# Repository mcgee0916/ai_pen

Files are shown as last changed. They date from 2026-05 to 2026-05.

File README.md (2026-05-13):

# AI PEN — 智慧軌跡筆
Gemini_Generated_Image_a84ghia84ghia84g

以 YOLOv4-Tiny 為推論核心的手寫數學式辨識裝置。使用者以實體筆在空中或紙上書寫數字與運算符號，裝置即時辨識並在 OLED 顯示計算結果。

\---

## 硬體規格

|元件|說明|
|-|-|
|MCU|HUB-8735Ultra|
|軌跡感測器|PAA5163D 光學感測器（Serial3，115200 baud）|
|顯示器|SSD1306 OLED（I2C）|
|按鈕|Pin 15，INPUT\_PULLUP|
|儲存|SD 卡（VFS FAT）|
|神經網路|NNObjectDetectionImage（板載 NPU）|

3D 列印外殼檔案：`ai\\\_pan\\\_frame.stl`

\---

## 辨識類別（14 類）

|類別|標籤|
|-|-|
|數字|`0` `1` `2` `3` `4` `5` `6` `7` `8` `9`|
|運算子|`add` (+)、`sub` (-)、`mul` (×)、`div` (÷)|

\---

## 目錄結構

```
.
├── ai\\\_pan/                  ← 主韌體（辨識 + 計算機）
│   ├── ai\\\_pan.ino
│   └── OledDisplay.h
├── ai\\\_pan\\\_collect/          ← 資料收集韌體（建立訓練集用）
│   ├── ai\\\_pan\\\_collect.ino
│   └── OledDisplay.h
├── NN\\\_MDL/
│   └── yolov4\\\_tiny.nb       ← 編譯完成的模型權重（燒錄至 SD 卡）
├── Unit\\\_testing/            ← 元件單元測試草稿
│   ├── BTN/                 ← 按鈕測試
│   ├── OLED/                ← OLED 顯示測試
│   ├── OLED\\\_BTN/            ← OLED + 按鈕整合測試
│   ├── PAA5163D/            ← 光學感測器測試
│   ├── ALL/                 ← 全元件整合測試
│   ├── HUB-PAA5163D\\\_Tracker.exe           ← Windows 軌跡可視化工具
│   └── HUB-PAA5163D\\\_路徑測試程式使用說明.pdf
├── YOLOv4Tiny\\\_AutoTrain.ipynb  ← Google Colab 訓練 Notebook
├── ai\\\_pan\\\_frame.stl            ← 外殼 3D 列印檔
└── AI-PEN.pptx                 ← 專案簡報
```

\---

## 環境建置

### 步驟 1：安裝 Arduino IDE

前往 [arduino.cc/en/software](https://www.arduino.cc/en/software) 下載並安裝 **Arduino IDE 1.8.19 或 2.x**。

### 步驟 2：新增開發板來源 URL

開啟 Arduino IDE → **檔案 → 偏好設定**，在「額外的開發板管理員網址」貼上：

```
https://github.com/ideashatch/HUB-8735/raw/main/amebapro2\_arduino/Arduino\_package/ideasHatch.json
```

點選 OK 儲存。

### 步驟 3：安裝開發板套件

**工具 → 開發板 → 開發板管理員**，搜尋 `ideasHatch` 或 `8735`，安裝 **HUB8735ULTRA**。
出現 `Platform ideasHatch:AmebaPro2@4.1.1-Release installed` 即完成。

### 步驟 4：安裝函式庫

**工具 → 管理函式庫**，分別搜尋並安裝：

|函式庫|用途|
|-|-|
|JPEGENC|AI辨識影像處理|

> `cJSON` 與 `NNObjectDetectionImage` 已包含在 ideasHatch SDK 中，無需額外安裝。

### 步驟 5：連接裝置與設定 COM Port

1. 用 USB Type-C 線連接 HUB 8735 Ultra 與電腦
2. **工具 → 開發板** 選擇 `HUB-8735\_ultra`（AmebaPro2 ARM 32-bits Boards - ideasHatch）
3. **工具 → 序列埠** 選擇對應 COM Port（Windows 裝置管理員確認 USB-SERIAL 編號）

\---

## 快速開始

### 1\. 準備 SD 卡

1. 將 SD 卡格式化為 **FAT32**
2. 將 `NN\_MDL\\yolov4\_tiny.nb` 連同資料夾複製到 SD 卡**根目錄**（路徑：`sd:NN\_MDL\\yolov4\_tiny.nb`）
3. 插入 HUB 8735 Ultra 的 SD 卡槽

### 2\. 硬體接線

|元件|元件接腳|HUB 8735 Ultra 接腳|
|-|-|-|
|HUB-PAA5163D|UART TX|Pin 5 (SERIAL3\_RX)|
|HUB-PAA5163D|UART RX|Pin 6 (SERIAL3\_TX)|
|HUB-PAA5163D|5V|5V|
|HUB-PAA5163D|GND|GND|
|SSD1306 OLED|SDA|Pin 0 (I2C1 SDA)|
|SSD1306 OLED|SCL|Pin 1 (I2C1 SCL)|
|SSD1306 OLED|VCC|5V|
|SSD1306 OLED|GND|GND|
|按鈕|S|Pin 15|
|按鈕|VCC|中間腳|
|按鈕|GND|GND|

### 3\. 燒錄韌體

開啟 `ai\\\_pan/ai\\\_pan.ino`，先讓裝置進入 Bootloader 模式再上傳：

**方法 A（按鍵操作）：**

1. USB Type-C 連接電腦
2. 長按「功能鍵」（不放開）
3. 按一下「Reset 鍵」後放開
4. 放開「功能鍵」→ 裝置進入 Bootloader 模式

**方法 B（短路 BOOT 引腳）：**

1. 短接 `BOOT\_MODE`（Pin 14）與 `BOOT\_V3P3`（3.3V）
2. 按下 Reset 後放開，再移除跳線

進入 Bootloader 後，點選 **上傳（Ctrl+U）**，輸出視窗出現 `Start Upload Flash → End Upload Flash` 即成功。上傳完成後按 Reset 重啟。

### 4\. 按鈕操作

|手勢|功能|
|-|-|
|長按（≥300 ms）按住|開始書寫軌跡|
|長按放開|結束書寫|
|單擊|清除目前筆畫|
|雙擊|觸發辨識|
|三擊|清除整條算式|
|四擊|重新初始化 PAA5163D|

### 4\. 書寫流程

1. **長按** → 書寫一個字元 → **放開**
2. 確認 OLED 預覽正確後 **雙擊** 觸發辨識
3. 辨識結果自動附加至算式；算式完整（數字＋運算子＋數字）時立即計算並顯示結果
4. **三擊**清除算式，重新開始

\---

## 訓練自訂模型

使用 `YOLOv4Tiny\\\_AutoTrain.ipynb`（需 Google Colab GPU）：

1. 在 Google Drive 建立 `yolov4\\\_tiny\\\_training/dataset/` 資料夾
2. 上傳圖片與對應 YOLO 格式 `.txt` 標註（`class\\\_id cx cy w h`，相對比例）
3. 在 Notebook 第一個 Cell 設定類別名稱與超參數
4. 依序執行所有 Cell；最佳權重輸出至 `yolov4\\\_tiny\\\_training/backup/`
5. 將 `.weights` 轉為 `.nb` 格式後複製至 SD 卡

\---

## 元件單元測試

開發或除錯時可先燒錄對應的單元測試草稿，確認硬體功能正常：

|草稿|測試目標|
|-|-|
|`Unit\\\_testing/BTN/BTN.ino`|按鈕長按 / 雙擊事件|
|`Unit\\\_testing/OLED/OLED.ino`|OLED 顯示輸出|
|`Unit\\\_testing/OLED\\\_BTN/OLED\\\_BTN.ino`|OLED + 按鈕整合|
|`Unit\\\_testing/PAA5163D/PAA5163D.ino`|PAA5163D 軌跡串流|
|`Unit\\\_testing/ALL/ALL.ino`|全元件整合|

Windows 上可用 `HUB-PAA5163D\\\_Tracker.exe` 將 PAA5163D 的 X/Y 串流可視化，確認感測器路徑是否正確。

\---

## SD 卡檔案說明

裝置啟動時會自動建立以下檔案：

|路徑|用途|
|-|-|
|`sd:/char-0001.jpg`|最近一次書寫的 JPEG 圖（推論輸入）|
|`sd:/char-0001.json`|NPU 輸出的偵測結果 JSON|
|`sd:/char\\\_list.txt`|推論圖片清單|
|`sd:/calc\\\_state.txt`|算式狀態（斷電保留）|
|`sd:/recognized/`|每次辨識後的 BMP 快照（用於資料收集）|

\---

## 開發環境

* Arduino IDE（含 Ameba RTL8720 BSP）
* &#x20;Google Colab（模型訓練）
* 相依函式庫：`JPEGENC`、`NNObjectDetectionImage`、`cJSON`、`SSD1306`

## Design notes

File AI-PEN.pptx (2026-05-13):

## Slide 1

AI-PEN

國產IC x ALgoHUB 智造實作日
HUB-8735Ultra x HUB-PAA5163D
HUB-PAA5163D 智慧軌跡筆

本專題使用的元件清單

HUB 8735 Ultra

開發板

HUB-PAA5163D
光學流量感測模組

感測器

SSD1306
128×32 OLED

顯示器

YOLOv4-Tiny
14 類手寫識別

AI 模型

瑞創框架科技股份有限公司
Recsframe Technology

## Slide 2

01

專題概述

本課程所需程式碼連結:
https://github.com/mcgee0916/ai_pen

這個專題要解決什麼問題？

SD 卡
模型 + 資料

HUB 8735 Ultra
主控板

YOLOv4-Tiny
AI 模型 (.nb)

推論

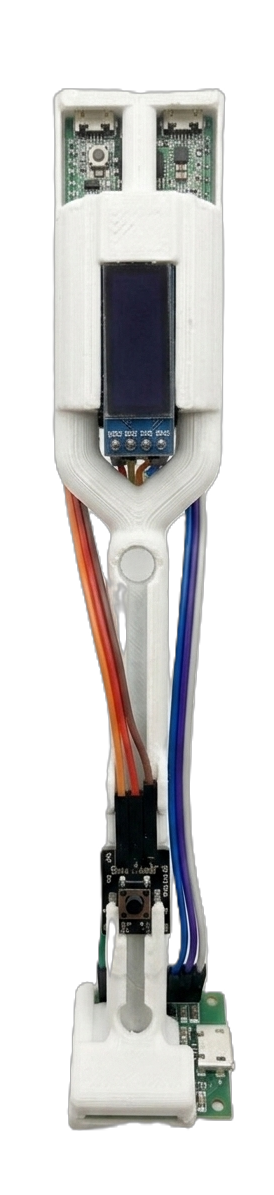
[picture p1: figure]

SSD1306
OLED

傳統計算機需要按鍵輸入，不夠直覺
→ 能不能用「手寫」來輸入數學算式？
→ 讓嵌入式裝置直接辨識手寫筆跡，自動計算結果

AI-PEN 的運作流程

微動按鈕模組

① 用筆在感測器上方書寫數字或運算符號
② HUB-PAA5163D 感測器捕捉筆尖移動軌跡（X/Y 座標）
③ HUB 8735 Ultra 將軌跡轉換成 128×128 點陣圖
④ 內建 YOLOv4-Tiny 模型辨識是哪個數字/符號
⑤ 累積算式後計算結果，顯示在 OLED 螢幕上

HUB-PAA5163D
光流感測器

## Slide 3

02

HUB 8735 Ultra — 介紹

HUB 8735 Ultra 是什麼？

HUB 8735 Ultra 是一款由振邦科技（WinsTec）推出的 AIoT 開發板，搭載瑞昱（Realtek）RTL8735B 晶片。
它的外型大小約為 Arduino Uno 的一半，但功能遠超傳統 Arduino：內建 Wi-Fi、BLE、攝影機介面，並支援硬體 AI 推論加速。
透過 Arduino IDE 開發，降低嵌入式 AI 的入門門檻。

功能 | HUB 8735 Ultra
處理器 | 32-bit ARM Cortex-A @ 500MHz
無線通訊 | Wi-Fi 2.4/5GHz BLE 4.2 RTSP
攝影機 | FPC 攝影機介面（最高 FHD 30fps）
AI 推論 | 支援多種辨識模型
電源 | USB Type-C 5V
尺寸 | 53 × 27 mm
其他 | LED燈、多組UART介面、I2C、SPI

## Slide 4

03

OLED VCC

HUB 8735 Ultra — 硬體規格與腳位

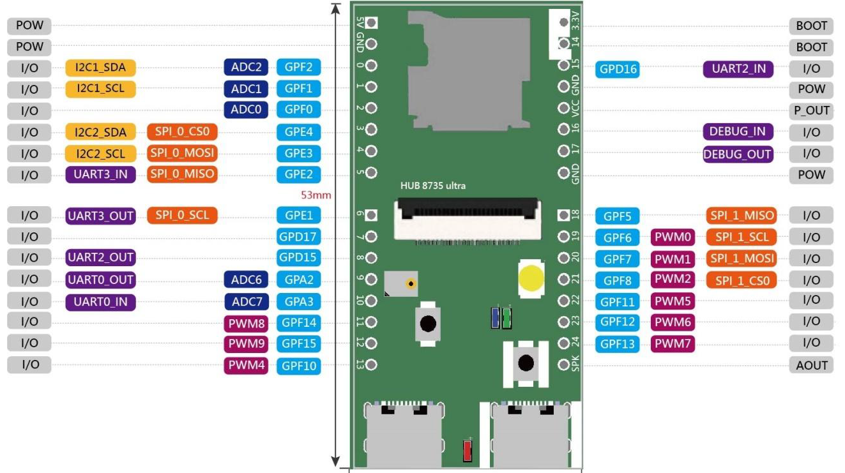
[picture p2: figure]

OLED GND

按鈕 VCC(中間)

按鈕 S

按鈕 GND(-)

OLED SDA
OLED SCL

PAA UART RX

PAA 5V

PAA UART TX

PAA GND

12-bit

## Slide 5

04

步驟 1

HUB 8735 Ultra — Arduino IDE 環境設定

安裝 Arduino IDE ≥ 1.8.19

前往 arduino.cc/en/Main/Software 下載並安裝。
建議使用 1.8.19 或 2.x 版，支援第三方開發板套件。

步驟 2

新增開發板來源 URL

開啟 Arduino IDE → 檔案 → 偏好設定
在「其他開發板管理員網址」貼上：
github.com/ideashatch/HUB-8735/raw/main/amebapro2_arduino/Arduino_package/ideasHatch.json

步驟 3

安裝開發板套件

工具 → 開發板 → 開發板管理員
搜尋「HUB 8735 ultra」或「ideasHatch」
找到「IdeasHatch Ameba Boards (32-bit ARM v8M @500MHz)」
安裝版本 4.0.10-Release 或更新版

步驟 4

連接裝置 COM Port 設置

用 USB Type-C 線連接電腦，並設置上傳程式預先流程。 （Windows 裝置管理員可確認 USB-SERIAL 的編號）
開發板 → AmebaPro2 ARM(32-bits) Boards - ideasHatch
→ 選擇「HUB-8735_ultra」

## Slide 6

04

步驟 1

HUB 8735 Ultra — Arduino IDE 環境設定

安裝 Arduino IDE ≥ 1.8.19

前往 arduino.cc/en/Main/Software 下載並安裝。
建議使用 1.8.19 或 2.x 版，支援第三方開發板套件。

https://www.arduino.cc/en/software/

1

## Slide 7

04

步驟 2

HUB 8735 Ultra — Arduino IDE 環境設定

新增開發板來源 URL

開啟 Arduino IDE → 檔案 → 偏好設定
在「其他開發板管理員網址」貼上：github.com/ideashatch/HUB-8735/raw/main/amebapro2_arduino/Arduino_package/ideasHatch.json
並點選OK 儲存設定

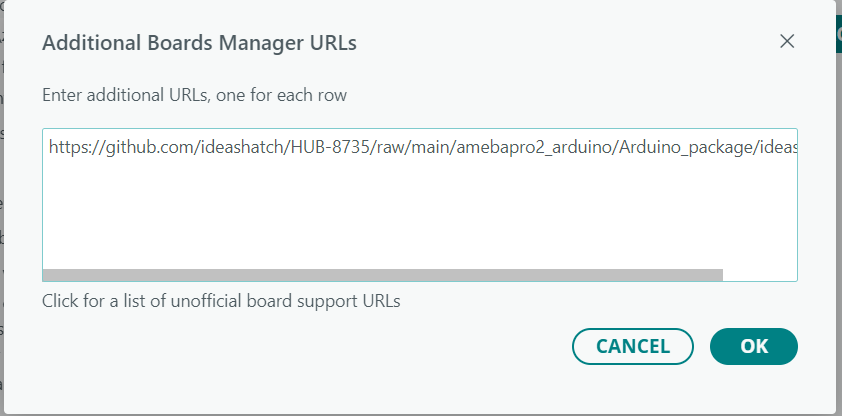
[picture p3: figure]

在空白處貼上網址

3

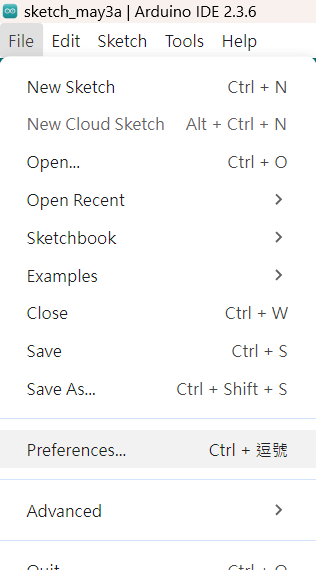
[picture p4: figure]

點選OK 儲存

4

1

2

github.com/ideashatch/HUB-8735/raw/main/amebapro2_arduino/Arduino_package/ideasHatch.json

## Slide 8

04

步驟 3

HUB 8735 Ultra — Arduino IDE 環境設定

安裝開發板套件

點選Board Manager 並在輸入框輸入” ideasHatch “ 或 ”8735”，將HUB8735ULTRA的韌體安裝。

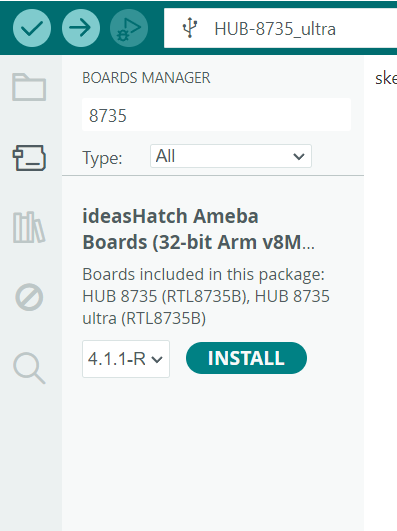
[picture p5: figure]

1

2

顯示Platform ideasHatch:AmebaPro2@4.1.1-Release installed
代表安裝完成!

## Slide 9

04

步驟 4

HUB 8735 Ultra — Arduino IDE 環境設定

連接裝置 COM Port 設置

用 USB Type-C 線連接電腦，並設置上傳程式預先流程。 （Windows 裝置管理員可確認 USB-SERIAL 的編號）

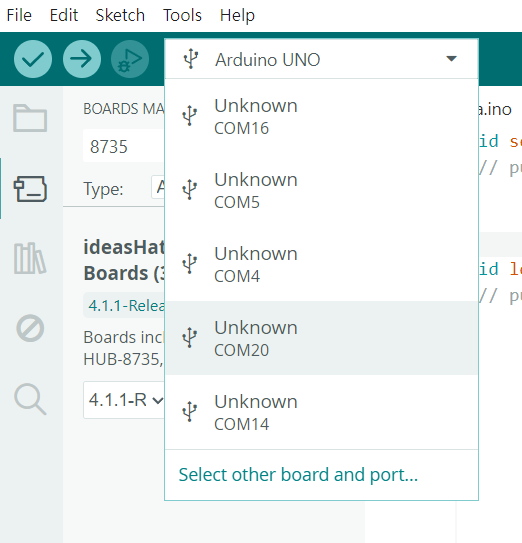
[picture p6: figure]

選擇設備連接後 出現的unknow COM port

BOARDS 輸入8735 並選擇HUB-8735_ultra

Type C線 連接HUB8735Ultra 及電腦

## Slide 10

05

HUB 8735 Ultra — 程式燒錄流程

燒錄準備：讓開發板進入 Bootloader（燒錄）模式

方法 A | 按鍵操作

方法 B | 短路 BOOT 引腳

① 用 USB Type-C 連接電腦
② 長按「功能鍵」（不放）
③ 按一下「Reset 鍵」後放開
④ 放開「功能鍵」
→ 裝置進入 Bootloader 模式

① 用跳線短接 BOOT_MODE（Pin 14）與 BOOT_V3P3（3.3V）

② 按下 Reset 鍵後放開

③ 移除跳線

→ 裝置進入 Bootloader 模式

（適合無法操作按鍵的場合）

程式上傳步驟

在 Arduino IDE 撰寫或開啟 .ino 專案

點選草稿碼 → 驗證/編譯（Ctrl+R），確認無錯誤

編寫程式

驗證編譯

依上方方法 A 或 B 讓裝置進入 Bootloader

進燒錄模式

點選上傳（Ctrl+U），觀察輸出視窗出現「Start Upload Flash → End Upload Flash」

上傳完成後按 Reset 鍵，程式開始執行

上傳

重啟

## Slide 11

05

HUB 8735 Ultra — 程式燒錄流程

燒錄準備：讓開發板進入 Bootloader（燒錄）模式

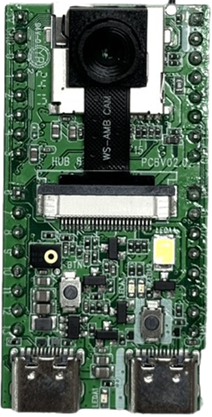
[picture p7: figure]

按住功能鍵

1

2

按住功能鍵狀態點擊
Reset鍵

方法 A | 按鍵操作

① 用 USB Type-C 連接電腦
② 長按「功能鍵」（不放）
③ 按一下「Reset 鍵」後放開
④ 放開「功能鍵」
→ 裝置進入 Bootloader 模式

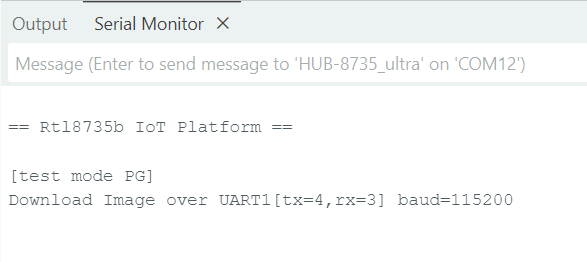
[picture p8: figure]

若成功進入Bootloader模式
可看到Serial Monitor顯示以上資訊

3

放開功能鍵

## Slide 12

06

HUB-PAA5163D — 光學流量感測原理

HUB-HUB-PAA5163D 模組外觀

PCB 板尺寸：約 35 × 35mm（郵票大小）
正面：HT32F49153 MCU + 感測器孔（朝下）
背面：PAA5163 光流鏡頭
接頭：USB-C（電源/UART）+ UART 引腳 + I2C 引腳

在 AI-PEN 中的接線方式

HUB-PAA5163D UART TX

HUB 8735 Ultra Pin 5 (SERIAL3_RX)

HUB-PAA5163D UART RX

HUB 8735 Ultra Pin 6 (SERIAL3_TX)

HUB-PAA5163D 5V

HUB-PAA5163D GND

HUB 8735 Ultra 5V

HUB 8735 Ultra GND

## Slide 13

06

HUB-PAA5163D — 光學流量感測原理

什麼是光學流量感測器（Optical Flow）？

光學流量感測器的原理類似光學滑鼠：
底部有一個微型攝影鏡頭，持續拍攝下方表面影像
比對連續兩張影像的像素移動，計算 X/Y 方向位移
輸出累積位移值（單位：counts per inch, CPI）
優點：不需要觸碰感測器，懸空即可感測
本專題應用：感測器朝下，筆在感測器下方 5–40mm 書寫

感測器 vs 滑鼠的比較

特性 | 電腦滑鼠 | HUB-HUB-PAA5163D
輸出 | 相對 X/Y 位移 | 累積 X/Y 座標
介面 | USB HID | UART / I2C
附加功能 | 無 | 陀螺儀 + 電子羅盤

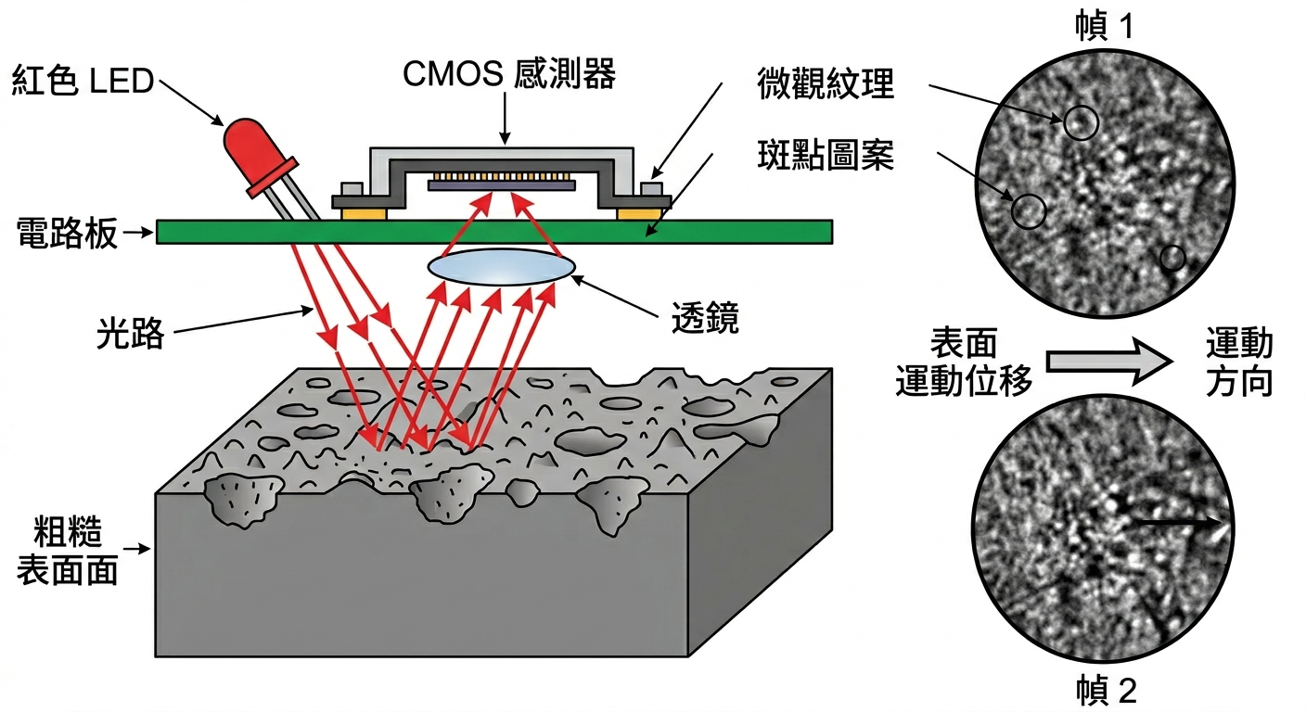
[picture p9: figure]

光學流量感測器

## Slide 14

06

HUB-PAA5163D — 光學流量感測原理

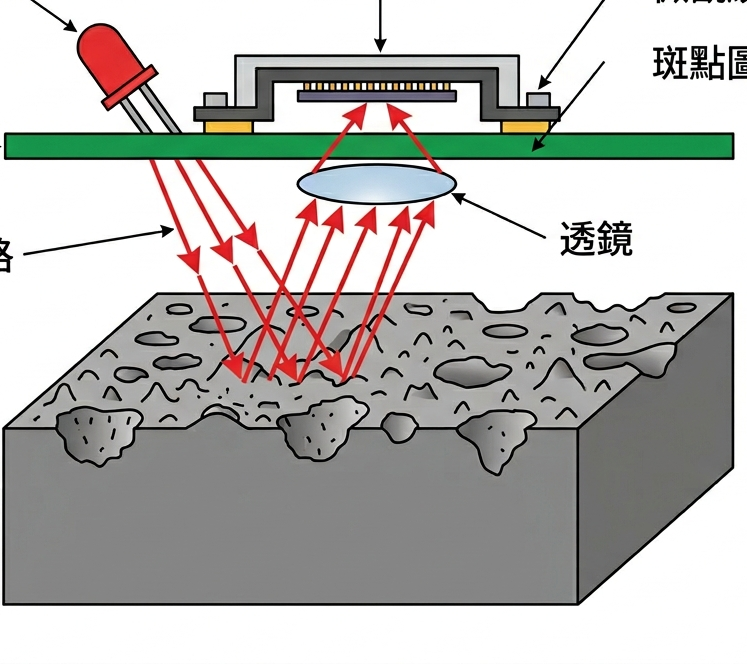
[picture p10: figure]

數據融合

讀取移動路徑

檢測傾腳、俯角

檢測方位

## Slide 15

07

HUB-PAA5163D — 硬體規格

MCU 控制器

PAA5163 光流感測器

1000 CPI-約 0.025 cm

ICM42688 六軸 IMU

QMC5883P 電子羅盤

型號

架構

HT32F49153

32-bit ARM Cortex-M4F

5 – 40 mm

解析度

感測高度

陀螺儀

加速度計

±2000 dps

±16g

量程

解析度

±8 Gauss

12-bit

時脈

144 MHz

>100 inch/s

最大速度

更新率

500 Hz

更新率

50 Hz

Flash

128KB

SPI（最高 2MHz）

介面

介面

I2C 400kHz

功能

傾斜補償

1KB（Flash 模擬）

電源規格

SRAM

EEPROM

48KB

5V（USB供電）

工作電壓

工作電流

約 150mA

功耗

約 0.75W

三種資料輸出模式（可切換）

ATR+ 原始模式

輸出原始位移量 dX, dY（整數）

ATX+ 座標模式

輸出累積絕對座標 X, Y

ATC+ 完整模式

輸出座標 + 陀螺儀 + 羅盤完整資料

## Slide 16

08

HUB-PAA5163D — 通訊介面：UART vs I2C

HUB-HUB-PAA5163D 提供兩種通訊介面，可根據應用選擇

特性 | UART / USB 介面 | I2C Slave 介面
主要用途 | 調試、測試、人機互動 | 嵌入式系統整合
控制方式 | AT 指令（文字） | 寄存器讀寫（二進位）
資料格式 | 文字或 JSON 格式 | 二進位結構體
通訊速率 | 115200 bps | 200 kHz
即時性 | 中（輪詢模式） | 高（直接記憶體存取）
適用場合 | PC 連接、除錯、示範 | MCU 對 MCU 通訊、量產品
啟用方式 | 上電預設啟用 | 偵測到 I2C 通訊自動切換
切換回 UART | 發送 UART 訊號即自動切換回 | 重新上電或硬體重置

本專題使用 UART 介面（Serial3, 115200bps）：MCU 解析 "X=NNN Y=NNN" 格式的文字輸出，取得手寫軌跡座標。
若偵測到 3 秒無資料，韌體會自動重新初始化感測器（發送 ATX+ 切換到座標模式）。

AI-PEN

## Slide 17

09

HUB-PAA5163D — AT 指令與資料格式

常用 AT 指令

說明

查詢通訊是否正常

指令

AT

資料輸出格式範例

JSON 模式（ATJ+ 後）

切換到原始模式（輸出 dX, dY）

ATR+

座標模式（ATX+）

切換到座標模式（輸出累積 X, Y）

ATX+

切換到完整模式（含 IMU、羅盤）

ATC+

A=5.4 X=0.0 Y=0.0 cA=304.2

{"A":6.1,"X":0.0,"Y":0.0,"cA":304.8}

啟用 JSON 格式輸出

ATJ+

韌體如何解析（ai_PEN.ino）

if (sscanf(line, "X=%d Y=%d", &x, &y) == 2) {
raw_pts[pt_count].x = x;
raw_pts[pt_count].y = y;
}

重設零點（目前位置設為 0,0）

AT0G+

重置感測器並重新初始化

ATNRST+OMT

設定報告間隔(50-1000)

ATRPT+

停止感測器資料輸出

ATM-

設定感測器距地面高度（影響精度）

ATH+[高度]

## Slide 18

09

HUB-PAA5163D — 設置

(確認裝置連線正常)

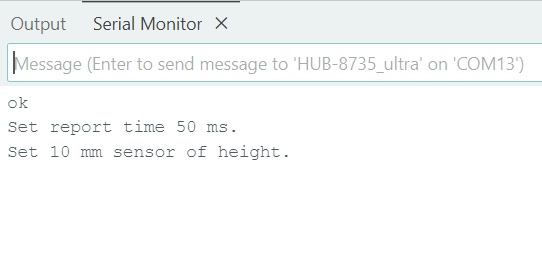
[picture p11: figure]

(設定回傳位置的時間間隔成功)

(設定感測的高度成功)

在Serial Monitor
依序輸入:

AT

atrpt+50

ath+10

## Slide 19

10

SSD1306 OLED — 規格與使用

Arduino 基本使用範例

SSD1306 是什麼？

SSD1306 是一款常見的單色 OLED 顯示器驅動 IC。
OLED（有機發光二極體）的特色：
· 自發光，不需背光，對比度高
· 低功耗，適合電池供電裝置
· 視角廣，響應速度快
· 本專題使用 128×32 像素尺寸

#include <Wire.h>
#include <Adafruit_GFX.h>
#include <Adafruit_SSD1306.h>

#define SCREEN_WIDTH 128
#define SCREEN_HEIGHT 32
Adafruit_SSD1306 display(SCREEN_WIDTH, SCREEN_HEIGHT, &Wire);

void setup() {
display.begin(SSD1306_SWITCHCAPVCC, 0x3C);
display.clearDisplay();
display.setTextColor(SSD1306_WHITE);
display.setTextSize(1);
display.setCursor(0, 0);
display.print("Hello AI-PEN!");
display.display(); // 必須呼叫才會更新畫面
}

硬體規格

128 × 32 像素（單色）

I2C（位址 0x3C 或 0x3D）

解析度

介面

3.3V / 5V 皆相容

電壓

I2C 接線（以 HUB 8735 Ultra 為例）

單色（白光 on 黑底）

Adafruit GFX + Adafruit SSD1306

顏色

HUB 8735 Pin 0（I2C1 SDA）

HUB 8735 Pin 1（I2C1 SCL）

HUB 8735 5V

HUB 8735 GND

OLED SDA

OLED SCL

OLED VCC

OLED GND

函式庫

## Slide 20

11

SSD1306 — OledDisplay.h 分區設計

為什麼要自定義 OledDisplay.h？

128×32 的螢幕空間有限，AI-PEN 需要同時顯示「筆跡預覽」和「算式 Token」，因此設計了 OledDisplay.h 將螢幕切成 2 個的區塊，各自獨立更新。

螢幕分區示意圖（128×32 總像素）

Section 1
筆跡預覽
32×32

Section 2
算式 Token
96×32

各區塊用途說明

左側最大區塊，顯示目前手寫筆跡的縮圖，或識別後的字符圖案

Section 0

右側三個區塊，各顯示一個已識別的算式 Token（數字或運算子）

Section 1–3

寫完一個字符雙擊識別後，Section 0 更新為 BMP 圖，Section 1/2/3 依序顯示算式

顯示邏輯

結果顯示在 Section 1–3，例如「3 + 5 = 8」，然後 sys_reset() 清除全部

計算完成

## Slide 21

11

SSD1306 — 接線

先將OLED卡入插槽

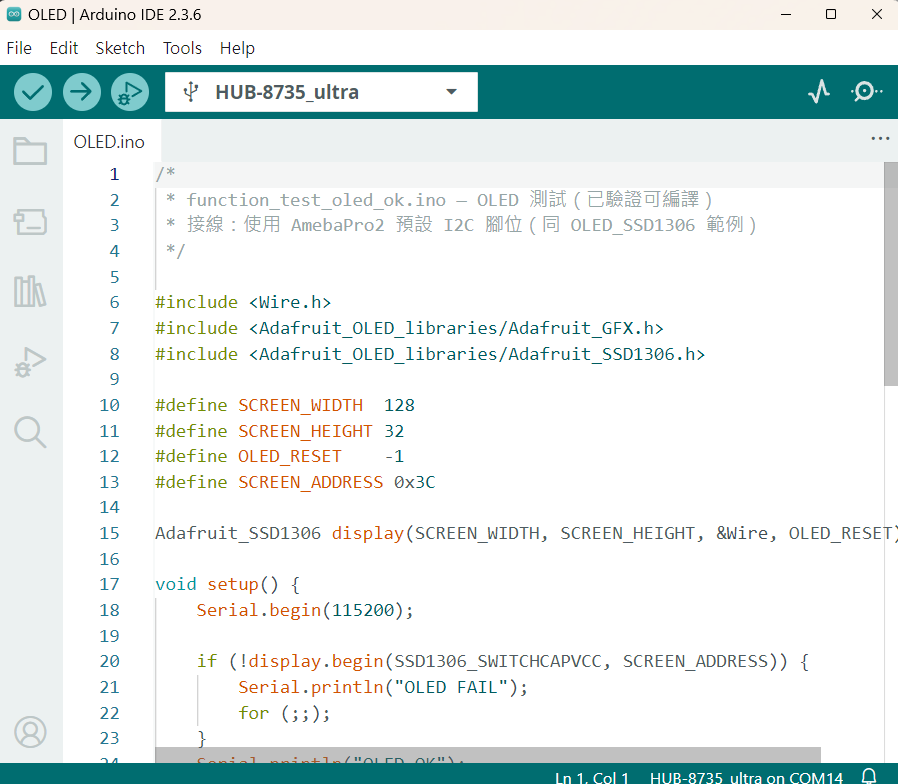
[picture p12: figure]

燒錄OLED 測試程式碼

OLED VCC
OLED GND
OLED SDA
OLED SCL

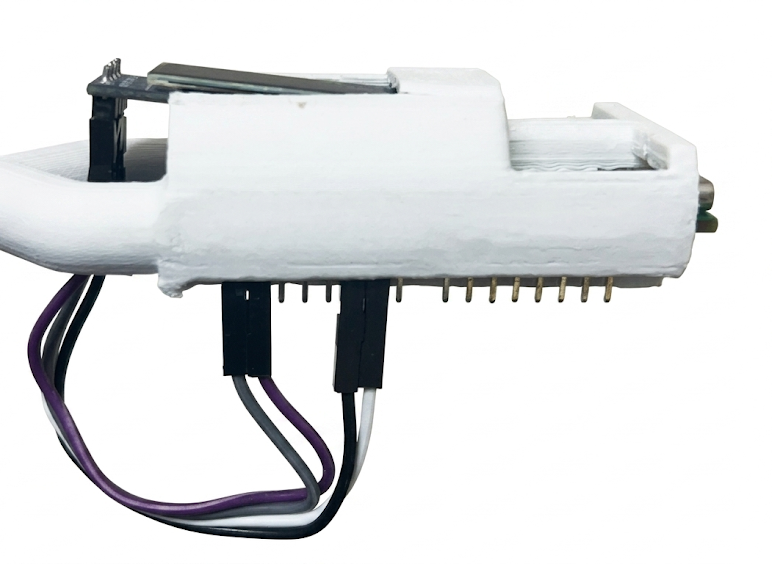
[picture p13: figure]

從筆桿中間位置穿孔連接杜邦線

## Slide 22

12

微動開關- 接線

將杜邦線先接上針腳
並將微動開關斜插進按鈕溝槽

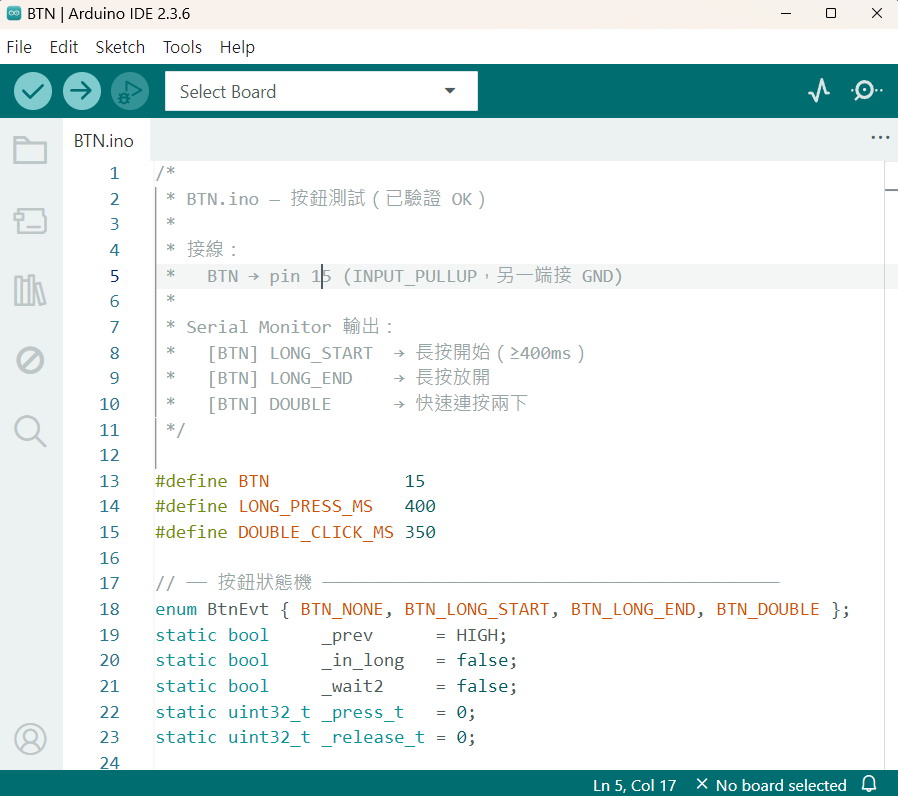
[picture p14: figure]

燒錄BTN程式碼確認接線
元件是否正常作動

按鈕 VCC(中間)

按鈕 S(15)

按鈕 GND(-)

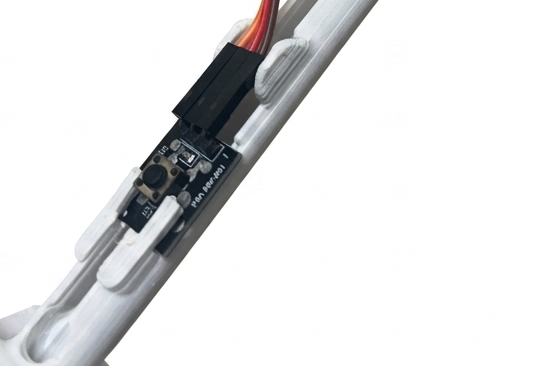
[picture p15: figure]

往前推之後，按鈕卡住即可

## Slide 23

13

HUB-PAA5163D - 接線

PAA 5V

PAA GND

PAA UART RX

PAA UART TX

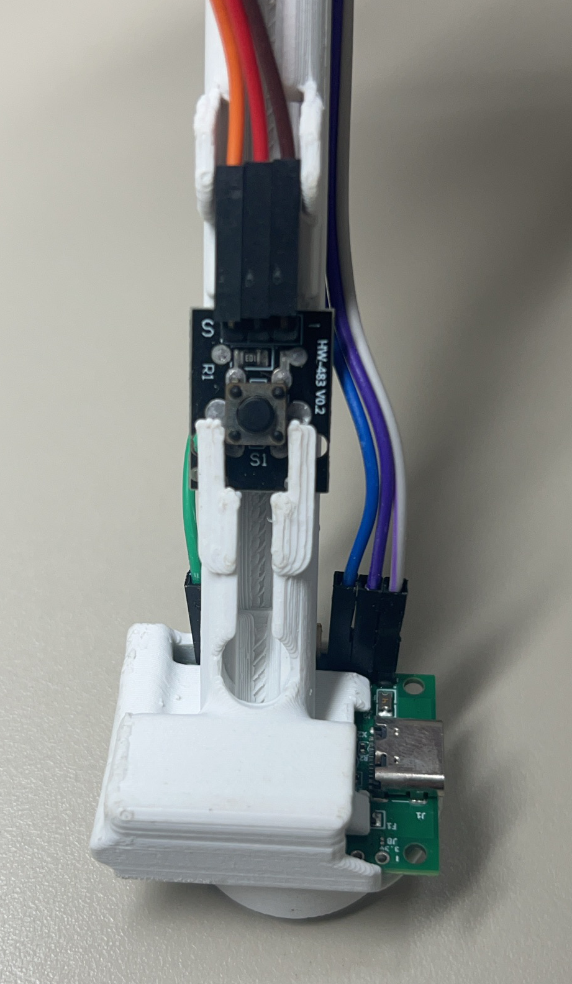
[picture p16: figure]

將PAA5163D插入元件孔位

將對應線接上(側面)

將對應線接上(背面)

(杜邦線同時會卡住PAA5163D使之不會鬆脫)

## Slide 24

13

HUB-PAA5163D - 接線

所有ai pen的所需元件都連接完成!

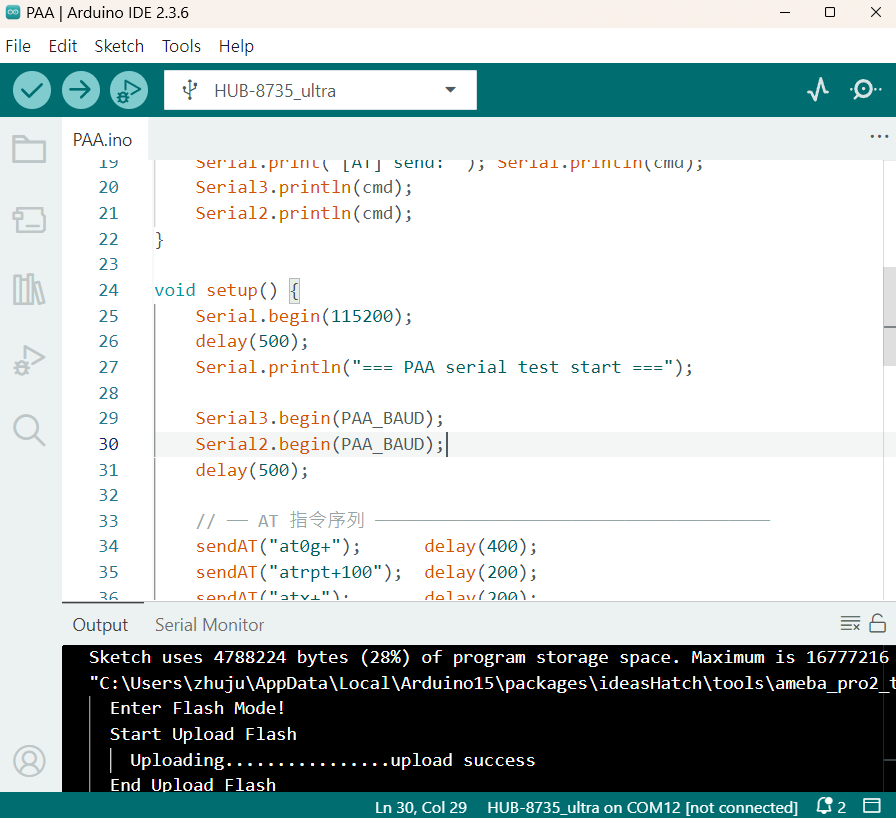
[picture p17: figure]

燒錄PAA.ino程式碼確認接線、元件是否正常作動

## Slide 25

15

目標偵測入門：YOLO 是什麼？

YOLO（You Only Look Once）

電腦視覺的三個層次

影像分類
(Classification)

這張圖片是什麼？
只有一個答案

例：貓 / 狗 / 數字

傳統目標偵測方法：先找可能有目標的區域，再分類（兩步驟，慢）
YOLO 的突破：一次性同時預測所有目標的位置和類別
→ 速度極快，適合即時應用
→ 單一神經網路完成所有工作

目標偵測
(Detection)

圖片裡有什麼？在哪裡？
可以有多個答案

例：3 個數字 + 2 個符號

YOLO 輸出什麼？

語義分割
(Segmentation)

每個像素屬於哪個類別？
最細粒度

例：略

x, y, width, height — 目標在圖中的位置和大小

預測是哪個類別（本專題：14 類）

預測結果的把握程度（0–1），本專題閾值 0.25

邊界框 (BBox)

類別 (Class)

AI-PEN 使用「目標偵測」：辨識 128×128 圖中的手寫字符及其位置

信心值 (Confidence)

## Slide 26

16

YOLOv4-Tiny 模型架構

為什麼選 YOLOv4-Tiny 而不是完整版 YOLOv4？

嵌入式裝置記憶體有限，完整版 YOLOv4 模型超過 200MB，而 YOLOv4-Tiny 只有約 23MB（ONNX），轉成 .nb 後約 4.4MB。
精簡後的網路仍能達到本任務所需的準確率（手寫數字/符號辨識，背景單純，目標明確）。

14 個輸出類別（obj.names）

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
本專題資料集規模

300 張/類，涵蓋全部 14 類，共4200張

資料集

訓練用

圖片數量

192x192

圖片尺寸

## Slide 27

17

韌體設計 — 按鈕事件詳解

GPIO 7（active-low, pull-up）按鈕的四種事件

BTN_LONG_START

長按 ≥ 300ms 開始時

觸發時機：按鈕持續按下超過 300ms
動作：IDLE → CAPTURING，清除 raw_pts[] 陣列，開始記錄座標

補充：可多次長按追加筆畫，例如寫「12」可分兩次長按

BTN_LONG_END

長按結束（放開按鈕）

觸發時機：長按後放開
動作：暫停記錄，保持 CAPTURING 狀態（等待下一筆畫或雙擊辨識）

補充：放開後 OLED Section 0 顯示目前筆跡縮圖

BTN_DOUBLE

快速雙擊（兩次按下間隔 < 350ms）

觸發時機：短時間內兩次按下
動作：CAPTURING → RECOGNIZING，呼叫 autoFit → renderToBmp → 存 BMP → AI 推論

補充：辨識完成後自動 sys_reset() 回到 IDLE

BTN_TRIPLE

快速三擊（三次按下間隔各 < 350ms）

觸發時機：短時間內三次按下
動作：清除所有算式狀態，刪除 calc_state.txt，OLED 清空，回到 IDLE

補充：相當於計算機的「AC（全部清除）」鍵

AI-PEN 手寫計算機 | Arduino 教學專題

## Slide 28

18

訓練資料收集

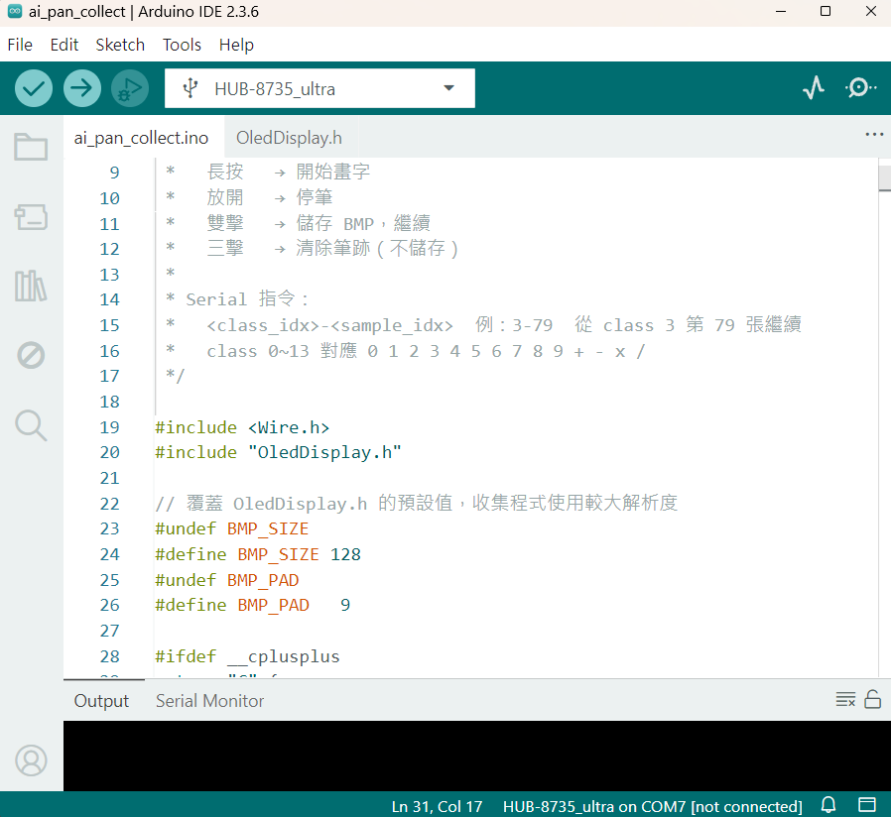
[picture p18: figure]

燒錄ai_pen_collection.ino開始我們的手寫資料收集

記得將SD卡接入裝置

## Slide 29

19

韌體設計 — 測試(ai_pen_collection.ino)

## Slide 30

20

YOLO v4 tiny訓練流程 – 資料標註(labelimg)

https://github.com/HumanSignal/labelImg/releases

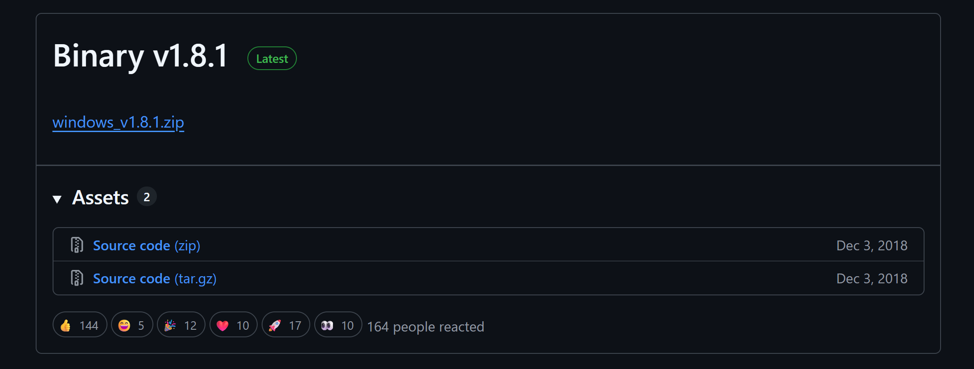
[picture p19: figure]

從開源的labelimg 進行下載、安裝

1

解壓縮後雙擊labelimg.exe 啟動標註程式

2

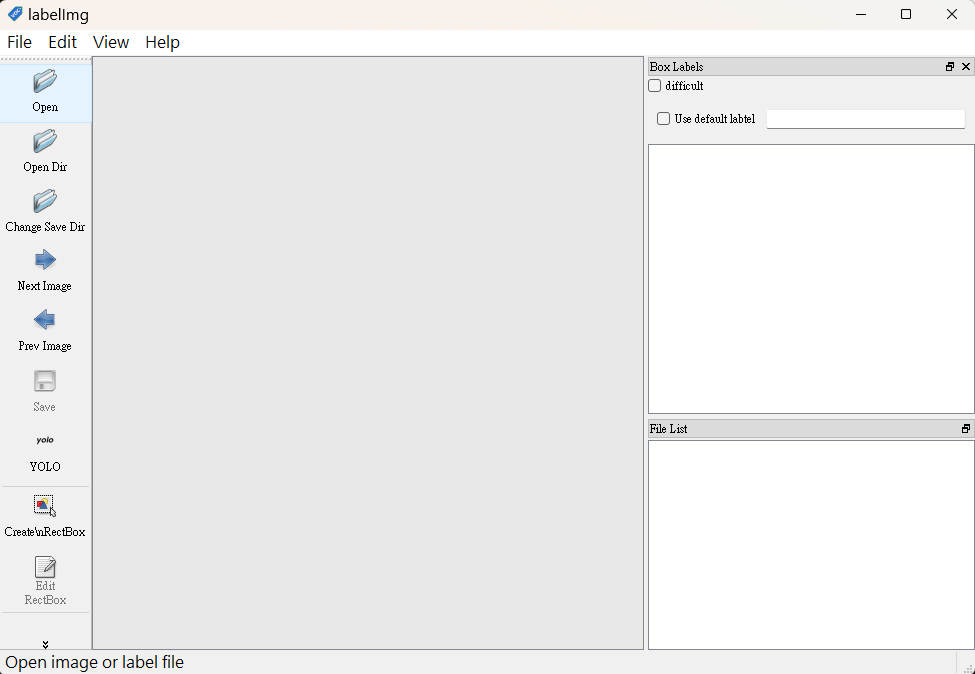
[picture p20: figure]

程式啟動後將點選標註類別為YOLO

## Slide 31

20

YOLO v4 tiny訓練流程 – 資料標註(labelimg)

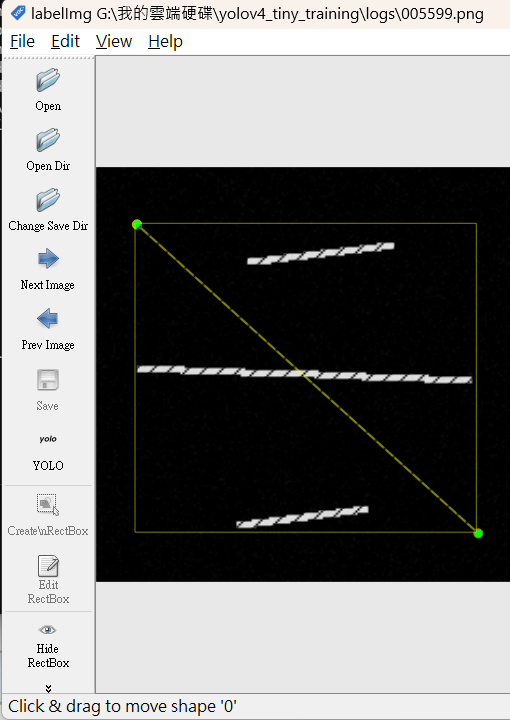
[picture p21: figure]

3

1

2

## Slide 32

21

YOLO v4 tiny訓練流程 – Colab 模型訓練

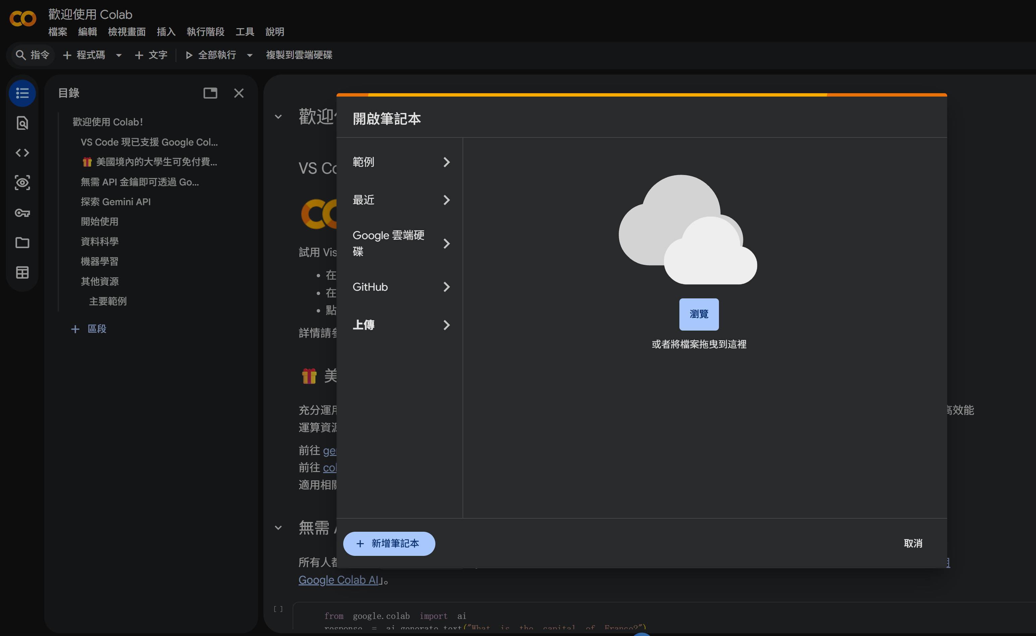
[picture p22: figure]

Google 搜尋 google colab 並選擇上傳程式碼

將本專題的colab 訓練程式上傳

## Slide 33

21

YOLO v4 tiny訓練流程 – Colab 模型訓練

YOLOv4Tiny_AutoTrain.ipynb

Step 1

掛載
Google Drive

Step 2

安裝 &
編譯 Darknet

Step 3

資料集
掃描分割

Step 4

生成
設定檔 cfg

Step 5

下載
預訓練權重

Step 6

開始
訓練

▶

▶

▶

▶

▶

drive.mount()
os.makedirs()

apt-get install
git clone + make

掃描圖片/標註配對
隨機分割 train/val/test

Colab執行過程會建立資料集 ，將圖片放進Dataset資料夾。

obj.names
obj.data
yolov4-tiny.cfg

yolov4-tiny
.conv.29

./darknet
detector train

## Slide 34

21

YOLO v4 tiny訓練流程 – 圖片路徑

建立後的 Drive 資料夾結構

MyDrive/
└── yolov4_tiny_training/
├── dataset/ ← 放圖片 + .txt
├── backup/ ← weights 輸出
└── logs/ ← log & 圖表

放圖片與 .txt 標註

weights 每 1000 iter 自動存

training_log.txt & loss_curve.png

分割比例視覺化（預設 70/20/10）

Train 70%

train.txt

Train 集圖片路徑清單

val.txt

Validation 集路徑清單

test.txt

Test 集清單（可選）

⚠ 圖片數 < BATCH_SIZE

請回設定區調低 BATCH_SIZE（建議 8 或 16）

Val
20%

10%

dataset/

backup/

logs/

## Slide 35

21

YOLO v4 tiny訓練流程 – 圖片路徑

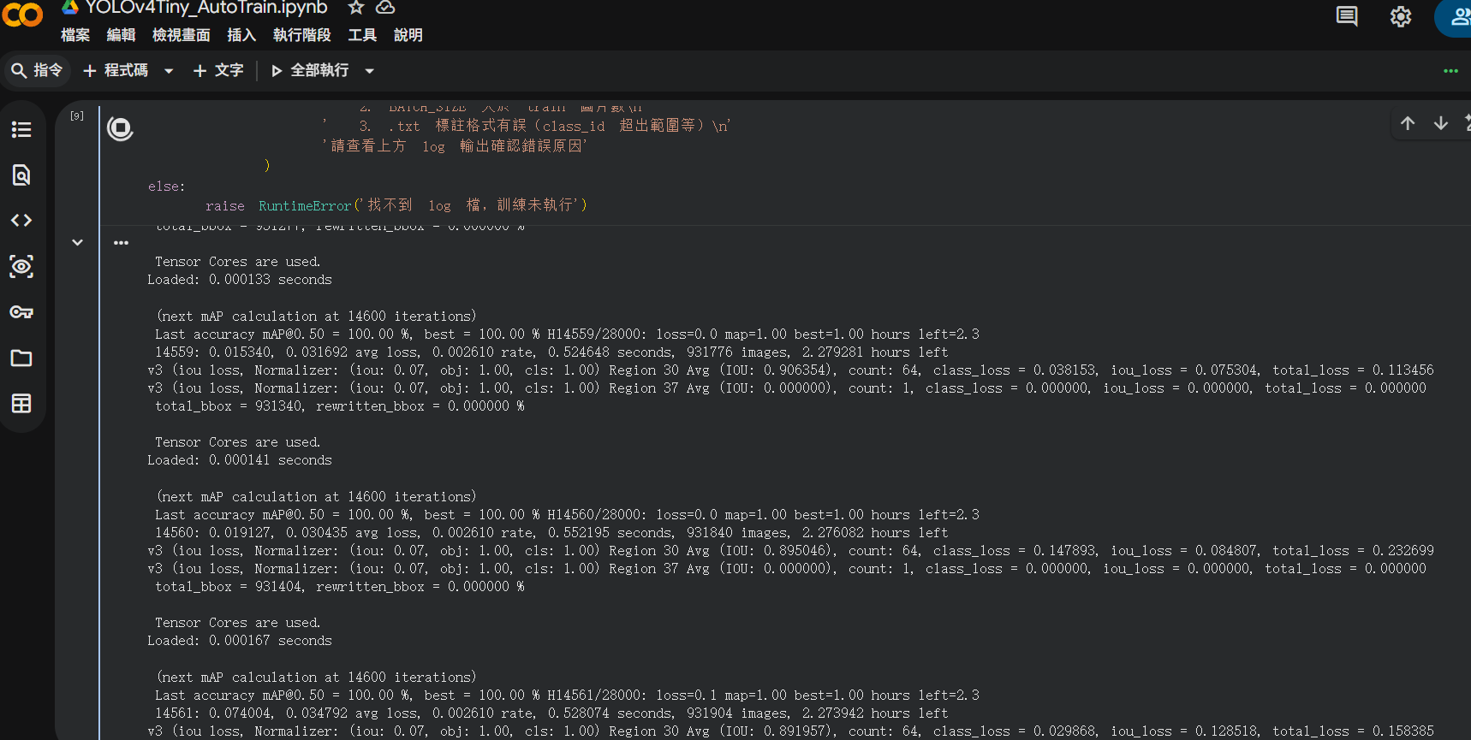
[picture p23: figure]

有看到此狀況 代表訓練正在進行

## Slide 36

22

模型格式轉換： yolov4_tiny .weight→ yolov4_tiny .nb

透過瑞昱的線上模型轉換工具，協助將weight檔案轉換成能讓hub8735ultra能使用的格式https://www.amebaiot.com/en/amebapro2-ai-convert-model/

使用此功能前需要先登入

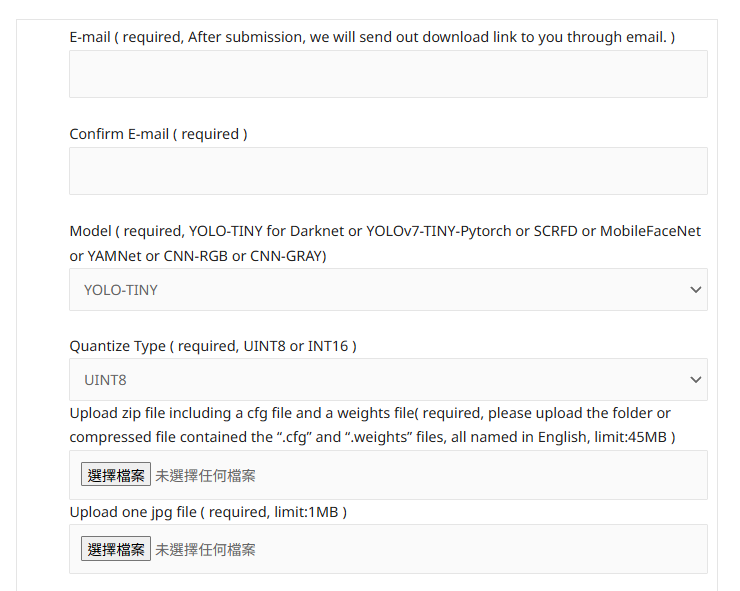
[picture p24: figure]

依照網站需求上傳相關檔案，並點選submit，並等待回信

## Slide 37

23

系統架構總覽

手寫輸入
HUB-PAA5163D

筆跡 X/Y 座標
Serial3 115200

座標處理
HUB 8735

autoFit()
renderToBmp()

AI 推論
YOLOv4-Tiny

BMP→SD→推論
讀取 JSON

算式解析
HUB 8735

appendToken()
evaluate()

結果顯示
SSD1306

OLED 128×32
I2C 介面

→

→

→

→

硬體連接一覽

裝置

介面

接至

參數

HUB-PAA5163D

SSD1306 OLED

UART Serial3

I2C

HUB 8735 Ultra Pin 5/6

HUB 8735 Ultra Pin 0/1

115200 bps

400 kHz

按鈕

GPIO

HUB 8735 Ultra Pin 15

active-low

SD 卡

SD 卡檔案結構

內建插槽

HUB 8735 Ultra

模型+資料

/sd/yolov4_tiny.nb

/sd/char.bmp

/sd/char.json

/sd/calc_state.txt

/sd/dataset/img_XXXXX.bmp

AI-PEN 手寫計算機 | Arduino 教學專題

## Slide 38

24

韌體設計 — 按鈕狀態機（Button FSM）

為什麼要設計狀態機？

手寫計算機需要區分不同操作模式：等待輸入、正在書寫、辨識中。用「狀態機」可以明確管理這些狀態之間的切換，避免邏輯混亂。

RUN_IDLE

待機狀態
等待長按按鈕

ai_PEN.ino 狀態機核心邏輯

RUN_CAPTURING

書寫狀態
持續記錄座標點

RUN_RECOGNIZING

辨識狀態
儲存BMP→AI推論

長按
→

長按
→

雙擊 → 辨識

辨識完成 → sys_reset() ↩ IDLE

void loop() {
processBtnEvents(); // 偵測按鈕事件
processSensorData(); // 讀取 HUB-PAA5163D 資料

switch (run_state) {
case RUN_IDLE: // 等待 BTN_LONG_START → 切換到 CAPTURING
case RUN_CAPTURING: // 累積座標點，等待 BTN_DOUBLE → 切換到 RECOGNIZING
case RUN_RECOGNIZING: // autoFit + renderToBmp + AI推論 → 解析結果 → sys_reset()
}
}

AI-PEN 手寫計算機 | Arduino 教學專題

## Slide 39

25

韌體設計 — autoFit() 座標正規化

autoFit() 核心程式碼片段

為什麼需要 autoFit()？

HUB-PAA5163D 輸出的是原始位移累積值，數值範圍不固定（可能是幾百到幾千）。
要讓 AI 模型能辨識，必須將筆跡統一縮放至 128×128 像素的畫布中。
autoFit() 負責這個正規化工作，同時保持字符的長寬比。

void autoFit() {
// 1. 找邊界框
int min_x=INT_MAX, max_x=INT_MIN;
int min_y=INT_MAX, max_y=INT_MIN;
for (int i=0; i<pt_count; i++) {
min_x = min(min_x, raw_pts[i].x);
max_x = max(max_x, raw_pts[i].x);
// ... same for y
}

// 2. 計算縮放比例（保持長寬比）
float bbox_w = max_x - min_x;
float bbox_h = max_y - min_y;
float scale = min(110.0f/bbox_w, 110.0f/bbox_h);

// 3. 正規化座標到 [9, 119]
float off_x = (128 - bbox_w*scale) / 2.0f;
float off_y = (128 - bbox_h*scale) / 2.0f;
for (int i=0; i<pt_count; i++) {
norm_pts[i].x = (raw_pts[i].x - min_x)*scale + off_x;
norm_pts[i].y = (raw_pts[i].y - min_y)*scale + off_y;
}
}

autoFit() 演算法步驟

找出所有座標點的最小/最大 X, Y 值（即原始筆跡的邊界框）

排除距離中心最遠的 5% 座標點（去雜訊）

① 計算邊界框

② 去除離群點

bbox_w / bbox_h，決定主要方向

③ 計算長寬比

scale = min(110/bbox_w, 110/bbox_h)（留 9px 邊距）

所有座標點：norm_x = (x - min_x) * scale + 9

④ 計算縮放比例

回傳 norm_pts[]，範圍保證在 [9, 119] 內

⑤ 平移+縮放

⑥ 輸出

AI-PEN 手寫計算機 | Arduino 教學專題

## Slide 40

26

韌體設計 — renderToBmp() 與 SD 卡 I/O

SD 卡 I/O 流程

renderToBmp() — 將筆跡繪製成點陣圖

① 初始化畫布：uint8_t bmp[128][128] = {0} 所有像素設為黑色（0）

② Bresenham 直線：對相鄰兩個正規化座標點，用 Bresenham 直線算法填充像素

③ 筆寬模擬：在每個繪製點周圍畫 3×3 正方形，模擬真實筆跡粗細

④ 存成 BMP：以 24-bit BMP 格式（RGB 各 8bit）寫入 SD 卡 /sd/char.bmp

Write

寫入 char.bmp

renderToBmp() 將 128×128 BMP 存到 /sd/char.bmp

AI

觸發推論

呼叫 NNObjectDetectionImage API，指定 /sd/char.bmp 作為輸入

void renderToBmp() {
uint8_t bmp[128][128] = {}; // 全黑

for (int i=0; i<pt_count-1; i++) {
// Bresenham 直線算法
bresenham(bmp,
norm_pts[i].x, norm_pts[i].y,
norm_pts[i+1].x, norm_pts[i+1].y);
}

// 寫入 24-bit BMP 到 SD 卡
saveBMP24("/sd/char.bmp", bmp, 128, 128);
}

Wait

等待結果

模型推論完成後，結果存入 /sd/char.json

Read

讀取 JSON

用 cJSON 函式庫解析 char.json，取得 class, confidence

UI

顯示結果

根據辨識結果呼叫 appendRecognizedToken()，更新 OLED

NN_MDL/yolov4_tiny.nb

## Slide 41

27

韌體設計 — 算式解析引擎

辨識完一個字符後，如何組成算式並計算？

程式碼示例

appendRecognizedToken() — 語法驗證

每次辨識完一個字符，呼叫此函式將 Token 加入算式。
語法規則（enforced）：
· 算式必須遵循「數字 [運算子 數字]」的模式
· 不允許連續兩個運算子
· 不允許算式開頭是運算子
· 違反規則的 Token 直接捨棄，OLED 顯示錯誤提示

void appendRecognizedToken(int cls, float conf) {
if (conf < 0.25) return; // 信心值門檻

bool is_op = (cls >= 10); // 10=+, 11=-, 12=x, 13=/
bool last_is_op = isLastTokenOperator();

// 語法驗證
if (expr_len == 0 && is_op) return; // 開頭不能是運算子
if (last_is_op && is_op) return; // 不能連續運算子

addToken(cls); // 加入算式
updateOLED(); // 更新顯示
saveState(); // 持久化到 SD 卡
}

evaluateExpression() — 計算

當算式完整後（數字 運算子 數字），雙擊觸發計算：
· 支援整數四則運算（+, -, ×, ÷）
· 除以零 → 顯示 "ERR"
· 結果存入 calc_state.txt 持久化

float evaluateExpression() {
float a = tokens[0], b = tokens[2];
switch (tokens[1]) {
case 10: return a + b; // +
case 11: return a - b; // -
case 12: return a * b; // x
case 13: if (b==0) { showError("ERR"); return 0; }
return a / b; // /
}
}

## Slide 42

28

系統整合與完整部署流程

資料集

訓練

YOLOv4Tiny_AutoTrain.ipynb

.nb
轉換

Realtek online converter

韌體
燒錄

Arduino IDE
→ .ino

SD卡
複製

/sd/
yolov4_tiny.nb

→

→

→

→

Arduino 必要函式庫

OLED 圖形基礎層

Adafruit GFX

部署 Checklist

✓

Adafruit SSD1306

✓

yolov4_tiny.nb 複製到 SD 卡 /sd/ 目錄

必要，模型不存在則無法推論

SD 卡格式化為 FAT32

HUB 8735 Ultra 要求 FAT32

cJSON

SSD1306 驅動

✓

Arduino IDE 選擇正確開發板與 COM Port

上傳前確認

NNObjectDetectionImage

JSON 解析（讀推論結果）

✓

進入燒錄模式再上傳

長按功能鍵 + Reset

Realtek AI 推論 API（平台SDK）

✓

上傳成功後 Reset 重啟

觀察 OLED 是否正常初始化

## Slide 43

29

學習重點回顧

感測器
HUB-PAA5163D

開發板
HUB 8735 Ultra

RTL8735B：32-bit ARM @500MHz，比 Uno 快 30 倍以上

內建 Wi-Fi/BLE，支援 AI 推論硬體加速

Arduino IDE 開發，降低嵌入式入門門檻

燒錄需要進入 Bootloader 模式（長按功能鍵 + Reset）

光學流量感測：底部鏡頭比對像素移動，輸出 X/Y 位移

UART 介面（115200bps）輸出"X=NNN Y=NNN"格式

整合 6 軸 IMU（ICM42688）+ 電子羅盤（QMC5883P）

感測高度 5–40mm，適合懸空手寫

AI 模型
YOLOv4-Tiny

嵌入式韌體
ai_PEN.ino

YOLO：一次前向傳播，同時偵測所有目標的位置+類別

14 個輸出類別：數字 0–9 + 四則運算子

訓練資料：手寫，每類 300 張

轉換流程：.weights → Realtek .nb

狀態機：IDLE → CAPTURING（長按） → RECOGNIZING（雙擊）

autoFit()：正規化座標到 128×128，保持長寬比

renderToBmp()：Bresenham 算法繪製筆跡到點陣圖

算式引擎：語法驗證 + 四則運算 + 除以零保護

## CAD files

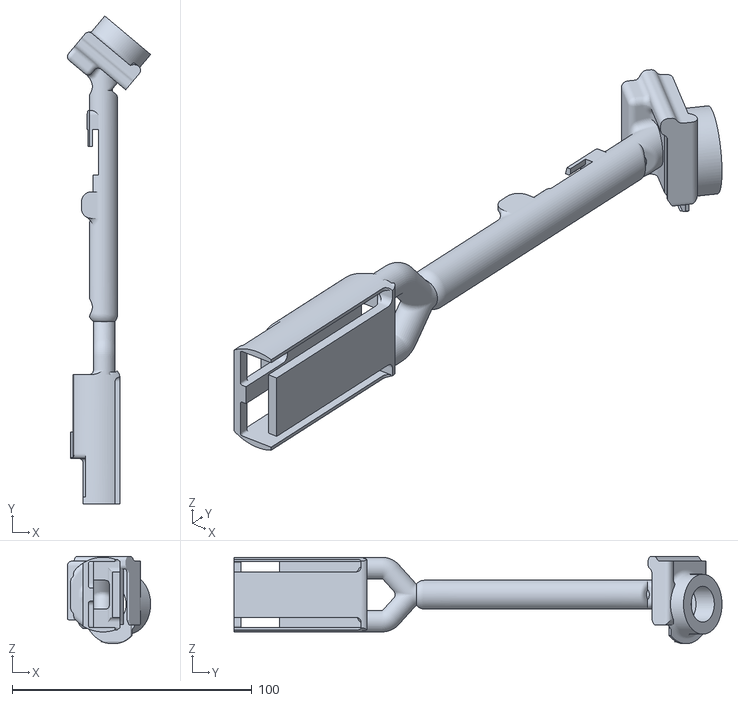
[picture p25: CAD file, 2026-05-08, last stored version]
ai_pan_frame_board.stl
34.8 x 203.6 x 36.5

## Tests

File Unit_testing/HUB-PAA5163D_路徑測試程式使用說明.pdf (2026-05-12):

# HUB-PAA5163D 路徑追蹤器 使用說明

版本：1.0 | 適用裝置：HUB-PAA5163D（光流 + IMU + 電子羅盤模組）

### 1. 軟體概述

本程式透過串列埠（COM）與 HUB-PAA5163D 模組通訊，即時顯示裝置的 2D 移動路徑、 IMU 姿態角、以及電子羅盤方向。

主要功能：

- 即時路徑繪製（支援 RAW / 座標 / 完整三種輸出模式）
- 電子羅盤指針顯示（畫布右下角）
- 羅盤校正引導（倒數計時）
- 路徑錄製與自動縮放
- 完整 AT 命令面板與 CMD 終端

### 2. 啟動與連線

1. 執行 HUB-PAA5163D_Tracker.exe
2. 在左側面板上方選擇 COM 埠（藍芽裝置已自動濾除，不會出現在清單中）
3. 選擇 鮑率（預設 115200，依裝置設定調整）
4. 按下 連線 按鈕（按鈕變紅表示已連線）
5. 右側 log 區域會顯示連線狀態及裝置回傳資料

⚠ 若 COM 埠清單為空，請確認裝置已插入並安裝驅動，再按 重新整理 更新清單。

### 3. AT 命令面板

左側面板提供分組按鈕，點按即自動送出對應 AT 命令。

### 3.1 基本

選項 | 命令 | 說明
測試 | AT | 測試通訊，回應 ok
版本 | AT? | 查詢韌體版本

從下拉選單選擇後按 執行。

### 3.2 輸出模式

按鈕 | 命令 | 說明
RAW | ATR+ | 輸出原始光流位移 dX/dY（未 經韌體處理）
座標 | ATX+ | 輸出韌體計算後的 X/Y 座標
完整 | ATC+ | 輸出 X/Y + Roll/Pitch + 羅盤角 度
停止 | AT- | 停止所有串流輸出

⚠ RAW 模式注意：由於輸出的是韌體未處理的原始值，噪音會直接累加，路徑在畫布上可能跳動或

飄移，屬正常現象。建議使用 ATX+ 或 ATC+ 以獲得穩定路徑。

### 3.3 校正

按鈕 | 命令 | 說明
原點 | AT0G+ | 重置 IMU、光流座標歸零，並 設定羅盤零點（需靜止約 200ms）
標準 | AT0C+8 | 啟動 20 秒羅盤校正（橢圓擬合 演算法）
極值 | AT0M+8 | 啟動 20 秒羅盤校正（最大最小 值演算法）
查詢 | ATI+C | 查詢目前感測器高度、間隔及羅 盤校正數據

羅盤校正步驟（標準 / 極值）
6. 按下 標準 或 極值 按鈕
7. log 區域開始顯示倒數（20 秒）
8. 在倒數期間，緩慢水平旋轉模組至少一整圈（可同時傾斜各方向）
9. 倒數結束後，裝置回傳校正結果（minX / maxX / minY / maxY / minZ / maxZ）
10. 校正數據自動儲存至裝置 EEPROM

⚠ 建議在電磁干擾較少的環境進行校正，並避免靠近金屬物體。

### 3.4 控制

按鈕 | 說明
MOV ○ / MOV ● | 切換 MOV Pin 輸出（綠色 = 啟用）
JSON ○ / JSON ● | 切換 JSON 格式輸出（綠色 = 啟用）
重置 | 執行 ATNRST+OMT，重置模組

### 4. 參數設定

感測器高度（ATH+）

- 輸入高度值（5～40 mm），按 設定 送出
- 按 -1 可遞減 1mm（ATH-）
- 高度影響光流位移的單位換算精度

輸出間隔（ATRPT+）

- 輸入間隔時間（50～1000 ms），按 設定 送出
- 預設 200ms（5 Hz）

羅盤校正數據手動寫入（ATI&）

- 格式：minX,maxX,minY,maxY,minZ,maxZ（6 個整數，逗號分隔）
- 例：-1234,1156,-1289,1098,-1456,1234
- 輸入後按 設定，裝置回應 Compass calibration data updated.

### 5. 路徑畫布

畫布中心（藍點）為座標原點（0, 0），X 軸向右，Y 軸向上。

縮放

- 拖動左側 縮放 滑桿調整顯示比例（0.1× ～ 20×）
- 右側數字顯示目前倍率

清除畫布

- 按 清除畫布（紅色按鈕）清除目前路徑，並重置座標累積值

錄製與自動縮放

- 按 錄製（● 變紅）開始記錄路徑座標
- 再次按下停止錄製
- 按 自動縮放 根據錄製路徑的邊界自動調整縮放比例，使路徑填滿畫布

電子羅盤指針

畫布右下角顯示即時羅盤指針：

- 紅色箭頭指向目前航向（0° = 北方，順時針）

- 下方數字顯示角度值（°）
⚠ 指針需裝置輸出 cA（羅盤角度）資料才會顯示，建議使用 ATX+ 或 ATC+ 模式。

### 6. RAW 模式進階設定

切換到 RAW（ATR+）模式時，左側面板提供額外選項：

設定 | 說明
RAW 角度補償 | 勾選後，dX/dY 會依 IMU 角度旋轉至世界座標 系（減少旋轉時的漂移）
Dead-zone | 忽略 |dX| + |dY| 小於此值的微小位移（預設 0， 建議設 2～5 以過濾靜止噪音）

### 7. CMD 終端

右側底部提供手動命令輸入列：

- 輸入任意 AT 命令後按 Enter 或 送出
- 使用 ↑ / ↓ 方向鍵瀏覽歷史命令
- 裝置回傳資料會即時顯示在 log 區域

### 8. 常見問題

問題 | 解法
連線後 log 沒有資料 | 確認輸出模式已啟動（按 ATX+ 或 ATC+）
路徑一直往單方向飄 | 執行 AT0G+ 重置原點；RAW 模式下嘗試開啟 Dead-zone
羅盤指針不動或數值異常 | 重新執行羅盤校正（標準 AT0C+8）
COM 埠清單沒有裝置 | 確認 USB 線插好，驅動已安裝，按重新整理
路徑很小看不清楚 | 調高縮放倍率，或使用自動縮放功能

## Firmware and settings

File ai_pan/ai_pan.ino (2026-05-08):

/*
 * ai_pan.ino
 * 單次辨識流程：
 * 1. 使用官方 ObjectDetectionImage 的 SD 圖片辨識機制。
 * 2. 每次只辨識一個 token。
 * 3. 辨識完成後把目前算式字串存進 SD。
 * 4. OLED 先顯示辨識圖，再直接 sys_reset 重啟。
 */

#include <Wire.h>
#include "OledDisplay.h"
#include <JPEGENC.h>
#include "NNObjectDetectionImage.h"

#ifdef __cplusplus
extern "C" {
#endif
#include "vfs.h"
#include "cJSON.h"
#include "sys_api.h"
#ifdef __cplusplus
}
#endif

#define BTN              15
#define LONG_PRESS_MS  300
#define DOUBLE_CLICK_MS 350

#define PAA_SERIAL  Serial3

#define PAA_BAUD    115200

#define SD_JPG_PATH    "sd:/char-0001.jpg"
#define SD_JSON_PATH   "sd:/char-0001.json"
#define SD_LIST_PATH   "sd:/char_list.txt"
#define SD_STATE_PATH  "sd:/calc_state.txt"
#define SD_RECOG_DIR   "sd:/recognized"

#define MAX_PTS         800
#define MAX_EXPR_CHARS   31

static const char *CALC_LABELS[14] = {
    "0","1","2","3","4","5","6","7","8","9",
    "add","sub","mul","div"
};
#define CALC_NUM_LABELS 14

OledDisplay oled;
NNObjectDetectionImage objDetImg;
static char filelist_name[] = "char_list.txt";

Pt   raw_pts[MAX_PTS];
bool stroke_start[MAX_PTS];
int  pt_count   = 0;
int  stroke_cnt = 0;

uint8_t bmp[BMP_SIZE][BMP_SIZE];
uint8_t recog_bmp[BMP_SIZE][BMP_SIZE];

struct FitCtx {
    int   px[MAX_PTS];
    int   py[MAX_PTS];
    float scale;
};
static FitCtx fit_ctx;
static float fit_work_x[MAX_PTS];
static float fit_work_y[MAX_PTS];

static bool is_writing         = false;
static bool first_pt_of_stroke = false;
static char calc_state[MAX_EXPR_CHARS + 1] = "";
enum BtnEvt { BTN_NONE, BTN_LONG_START, BTN_LONG_END, BTN_SINGLE, BTN_DOUBLE, BTN_TRIPLE, BTN_QUAD };
static bool     _prev_btn    = HIGH;
static bool     _in_long     = false;
static uint32_t _press_t     = 0;
static uint32_t _last_click_t = 0;
static uint8_t  _click_count  = 0;

enum RunState { RUN_IDLE, RUN_CAPTURING, RUN_RECOGNIZING };
static RunState run_state = RUN_IDLE;
static bool recognize_pending = false;

char uart_buf[128];
int  uart_len = 0;
char cmd_buf[128];
int  cmd_len = 0;
static uint32_t debug_run_seq = 0;
static uint16_t debug_pts_dropped = 0;
static int debug_last_json_count = -1;
static int debug_last_best_area_cls = -1;
static float debug_last_best_area = -1.0f;
static int debug_last_best_score_cls = -1;
static float debug_last_best_score = -1.0f;
static uint32_t debug_last_json_checksum = 0;
static int debug_last_json_len = -1;

static bool isDigitChar(char c) {
    return c >= '0' && c <= '9';
}

static bool isOperatorChar(char c) {
    return c == '+' || c == '-' || c == '*' || c == '/';
}

// 將 CALC_LABELS 的運算子字串轉為內部單字元（'+' '-' '*' '/'）
static char labelToOpChar(const char *label) {
    if (strcmp(label, "add") == 0) return '+';
    if (strcmp(label, "sub") == 0) return '-';
    if (strcmp(label, "mul") == 0) return '*';
    if (strcmp(label, "div") == 0) return '/';
    return '\0';
}

// 取得 OLED 顯示用字元（數字直接取首字元，運算子映射回可見 ASCII）
static char labelToDisplayChar(const char *label) {
    if (!label || label[0] == '\0') return '?';
    if (label[1] == '\0') return label[0];
    return labelToOpChar(label);
}

static char toUpperAscii(char c) {
    return (c >= 'a' && c <= 'z') ? (char)(c - 'a' + 'A') : c;
}

static bool containsOK(const char *s) {
    if (!s) return false;
    for (int i = 0; s[i] != '\0' && s[i + 1] != '\0'; i++) {
        if (toUpperAscii(s[i]) == 'O' && toUpperAscii(s[i + 1]) == 'K') {
            return true;
        }
    }
    return false;
}

static void showStatusScreen(const char *line1, const char *line2) {
    oled.dev.clearDisplay();
    oled.dev.setTextSize(1);
    oled.dev.setTextColor(SSD1306_WHITE);
    oled.dev.setCursor(0, 0);
    if (line1 && line1[0] != '\0') oled.dev.println(line1);
    if (line2 && line2[0] != '\0') oled.dev.println(line2);
    oled.dev.display();
}

static int compareFloatAsc(const void *a, const void *b) {
    float fa = *(const float *)a;
    float fb = *(const float *)b;
    if (fa < fb) return -1;
    if (fa > fb) return 1;
    return 0;
}

static bool waitForPAAOK(uint32_t timeout_ms, const char *log_prefix) {
    char rbuf[64];
    int rlen = 0;
    uint32_t t0 = millis();

    while (millis() - t0 < timeout_ms) {
        if (PAA_SERIAL.available()) {
            char c = (char)PAA_SERIAL.read();
            if (c == '\n' || c == '\r') {
                if (rlen > 0) {
                    rbuf[rlen] = '\0';
                    if (log_prefix && log_prefix[0] != '\0') {
                        Serial.print(log_prefix); Serial.println(rbuf);
                    }
                    if (containsOK(rbuf)) return true;
                    rlen = 0;
                }
            } else if (rlen < (int)sizeof(rbuf) - 1) {
                rbuf[rlen++] = c;
            }
        }
    }

    if (rlen > 0) {
        rbuf[rlen] = '\0';
        if (log_prefix && log_prefix[0] != '\0') {
            Serial.print(log_prefix); Serial.println(rbuf);
        }
        if (containsOK(rbuf)) return true;
    }
    return false;
}

static int findEqualIndex(const char *s) {
    for (int i = 0; s[i] != '\0'; i++) {
        if (s[i] == '=') return i;
    }
    return -1;
}

static int findOperatorIndex(const char *s) {
    for (int i = 0; s[i] != '\0'; i++) {
        if (isOperatorChar(s[i])) return i;
    }
    return -1;
}

static void copySpan(char *dst, size_t dstlen, const char *src, int count) {
    if (dstlen == 0) return;
    if (count < 0) count = 0;
    int n = count;
    if (n > (int)dstlen - 1) n = (int)dstlen - 1;
    memcpy(dst, src, n);
    dst[n] = '\0';
}

void renderExprSections() {
    char display_text[MAX_EXPR_CHARS * 2 + 4] = "";

    if (calc_state[0] != '\0') {
        int eq_idx = findEqualIndex(calc_state);
        int op_idx = findOperatorIndex(calc_state);

        if (eq_idx >= 0) {
            strncpy(display_text, calc_state, sizeof(display_text) - 1);
            display_text[sizeof(display_text) - 1] = '\0';
        } else if (op_idx < 0) {
            snprintf(display_text, sizeof(display_text), "%s=%s", calc_state, calc_state);
        } else {
            strncpy(display_text, calc_state, sizeof(display_text) - 1);
            display_text[sizeof(display_text) - 1] = '\0';
        }
    }

    oled.drawExprText(display_text, millis());
}

void redrawStateScreen(bool show_bitmap) {
    oled.dev.clearDisplay();
    if (show_bitmap) {
        oled.drawSec0Bitmap(bmp);
    } else {
        oled.clearSec(0);
    }
    renderExprSections();
    oled.drawDividers();
    oled.dev.display();
}

void showNoRecognitionScreen() {
    oled.dev.clearDisplay();
    oled.drawSec0Bitmap(bmp);
    oled.drawExprText("NO RESULT", millis());
    oled.drawDividers();
    oled.dev.display();
}

void saveCalcState() {
    FILE *fp = fopen(SD_STATE_PATH, "w");
    if (!fp) {
        Serial.println("[SD] cannot write calc_state.txt");
        return;
    }
    fputs(calc_state, fp);
    fclose(fp);
}

void clearCalcState() {
    calc_state[0] = '\0';
    saveCalcState();
    clearStrokes();
    recognize_pending = false;
    is_writing = false;
    first_pt_of_stroke = false;
    run_state = RUN_IDLE;
    redrawStateScreen(false);
}

void loadCalcState() {
    calc_state[0] = '\0';
    FILE *fp = fopen(SD_STATE_PATH, "r");
    if (!fp) return;

    int len = (int)fread(calc_state, 1, MAX_EXPR_CHARS, fp);
    fclose(fp);
    if (len < 0) len = 0;
    calc_state[len] = '\0';

    while (len > 0 &&
           (calc_state[len - 1] == '\r' || calc_state[len - 1] == '\n' || calc_state[len - 1] == ' ')) {
        calc_state[--len] = '\0';
    }
}

bool evaluateExpression(const char *expr_text, char *result, size_t result_len) {
    if (!expr_text || !result || result_len == 0) return false;

    int op_idx = findOperatorIndex(expr_text);
    if (op_idx <= 0) return false;

    char lhs[16] = "";
    char rhs[16] = "";
    copySpan(lhs, sizeof(lhs), expr_text, op_idx);
    strncpy(rhs, expr_text + op_idx + 1, sizeof(rhs) - 1);
    rhs[sizeof(rhs) - 1] = '\0';

    if (lhs[0] == '\0' || rhs[0] == '\0') return false;

    long a = atol(lhs);
    long b = atol(rhs);
    char op = expr_text[op_idx];
    long value = 0;

    switch (op) {
        case '+': value = a + b; break;
        case '-': value = a - b; break;
        case '*': value = a * b; break;
        case '/':
            if (b == 0) {
                strncpy(result, "ERR", result_len - 1);
                result[result_len - 1] = '\0';
                return true;
            }
            value = a / b;
            break;
        default:
            return false;
    }

    snprintf(result, result_len, "%ld", value);
    return true;
}

void finalizeExpressionIfReady() {
    if (findEqualIndex(calc_state) >= 0) return;

    int op_idx = findOperatorIndex(calc_state);
    if (op_idx <= 0) return;
    if (calc_state[op_idx + 1] == '\0') return;
    if (!isDigitChar(calc_state[strlen(calc_state) - 1])) return;

    char result[16] = "";
    if (!evaluateExpression(calc_state, result, sizeof(result))) return;

    char expr_copy[MAX_EXPR_CHARS + 1];
    strncpy(expr_copy, calc_state, sizeof(expr_copy) - 1);
    expr_copy[sizeof(expr_copy) - 1] = '\0';

    size_t expr_len = strlen(expr_copy);
    size_t result_len = strlen(result);
    if (expr_len + 1 + result_len > MAX_EXPR_CHARS) return;

    memcpy(calc_state, expr_copy, expr_len);
    calc_state[expr_len] = '=';
    memcpy(calc_state + expr_len + 1, result, result_len);
    calc_state[expr_len + 1 + result_len] = '\0';
}

bool appendRecognizedToken(const char *token) {
    if (!token || token[0] == '\0') return false;

    char ch;
    if (token[1] == '\0') {
        ch = token[0];                 // 數字 "0"–"9"
    } else {
        ch = labelToOpChar(token);     // "add"→'+' "sub"→'-' "mul"→'*' "div"→'/'
        if (ch == '\0') return false;
    }
    int eq_idx = findEqualIndex(calc_state);

    if (eq_idx >= 0) {
        char result_part[MAX_EXPR_CHARS + 1] = "";
        strncpy(result_part, calc_state + eq_idx + 1, sizeof(result_part) - 1);
        result_part[sizeof(result_part) - 1] = '\0';

        if (isOperatorChar(ch) && strcmp(result_part, "ERR") != 0 && result_part[0] != '\0') {
            size_t result_len = strlen(result_part);
            if (result_len + 1 > MAX_EXPR_CHARS) return false;
            memcpy(calc_state, result_part, result_len);
            calc_state[result_len] = ch;
            calc_state[result_len + 1] = '\0';
            return true;
        } else if (isDigitChar(ch)) {
            calc_state[0] = ch;
            calc_state[1] = '\0';
            return true;
        } else {
            return false;
        }
    }

    int len = (int)strlen(calc_state);
    int op_idx = findOperatorIndex(calc_state);

    if (isDigitChar(ch)) {
        if (op_idx < 0 && len == 1 && calc_state[0] == '0') {
            calc_state[0] = ch;
            calc_state[1] = '\0';
            finalizeExpressionIfReady();
            return true;
        }
        if (op_idx >= 0 && calc_state[op_idx + 1] == '0' && calc_state[op_idx + 2] == '\0') {
            calc_state[op_idx + 1] = ch;
            calc_state[op_idx + 2] = '\0';
            finalizeExpressionIfReady();
            return true;
        }
        if (len >= MAX_EXPR_CHARS) return false;
        calc_state[len] = ch;
        calc_state[len + 1] = '\0';
        finalizeExpressionIfReady();
        return true;
    }

    if (!isOperatorChar(ch)) return false;
    if (len == 0) return false;

    if (op_idx < 0) {
        if (len >= MAX_EXPR_CHARS) return false;
        calc_state[len] = ch;
        calc_state[len + 1] = '\0';
        return true;
    }

    if (isOperatorChar(calc_state[len - 1])) {
        calc_state[len - 1] = ch;
        return true;
    }

    return false;
}

BtnEvt pollButton() {
    bool cur = digitalRead(BTN);
    uint32_t now = millis();
    BtnEvt evt = BTN_NONE;

    if (cur == LOW && _prev_btn == HIGH) {
        _press_t = now;
    } else if (cur == HIGH && _prev_btn == LOW) {
        if (_in_long) {
            _in_long = false;
            evt = BTN_LONG_END;
        } else if (now - _press_t < LONG_PRESS_MS) {
            if (_click_count < 4) _click_count++;
            _last_click_t = now;
        }
    } else if (cur == LOW) {
        if (!_in_long && (now - _press_t >= LONG_PRESS_MS)) {
            _in_long = true;
            _click_count = 0;
            evt = BTN_LONG_START;
        }
    } else if (_click_count > 0 && (now - _last_click_t >= DOUBLE_CLICK_MS)) {
        if      (_click_count == 1) evt = BTN_SINGLE;
        else if (_click_count == 2) evt = BTN_DOUBLE;
        else if (_click_count == 3) evt = BTN_TRIPLE;
        else if (_click_count >= 4) evt = BTN_QUAD;
        _click_count = 0;
    }

    _prev_btn = cur;
    return evt;
}

void handleButtonEvent(BtnEvt evt) {
    switch (evt) {
        case BTN_LONG_START:
            if (run_state == RUN_RECOGNIZING || recognize_pending) {
                break;
            }
            is_writing = true;
            first_pt_of_stroke = true;
            stroke_cnt++;
            run_state = RUN_CAPTURING;
            break;

        case BTN_LONG_END:
            if (!is_writing) break;
            is_writing = false;
            if (run_state != RUN_RECOGNIZING) run_state = RUN_IDLE;
            break;

        case BTN_SINGLE:
            if (run_state == RUN_RECOGNIZING) break;
            clearStrokes();
            Serial.println("[BTN] clear bmp");
            break;

        case BTN_DOUBLE:
            if (run_state == RUN_RECOGNIZING || recognize_pending) {
                break;
            }
            recognize_pending = true;
            if (is_writing) {
                is_writing = false;
                first_pt_of_stroke = false;
            }
            break;

        case BTN_TRIPLE:
            if (run_state == RUN_RECOGNIZING) {
                break;
            }
            clearCalcState();
            break;

        case BTN_QUAD:
            if (run_state == RUN_RECOGNIZING || is_writing) {
                break;
            }
            showStatusScreen("PAA PROCESSING", "REINIT...");
            if (!initPAA()) {
                showStatusScreen("PAA ERROR", "CHECK SENSOR");
                Serial.println("[PAA] manual reinit failed");
            } else {
                redrawStateScreen(false);
            }
            break;

        default:
            break;
    }
}

void compassCalibrate() {
    // 停止感測器輸出
    while (PAA_SERIAL.available()) PAA_SERIAL.read();
    PAA_SERIAL.println("at-");
    delay(300);
    while (PAA_SERIAL.available()) PAA_SERIAL.read();

    // 發送校正指令（20 秒橢圓擬合）
    PAA_SERIAL.println("at0c+8");

    // OLED 倒數顯示，同時收集回應
    uint32_t start = millis();
    bool got_ok = false;
    char cal_resp[128] = "";
    int  cal_resp_len  = 0;

    while (millis() - start < 25000) {
        int remain = 20 - (int)((millis() - start) / 1000);
        if (remain < 0) remain = 0;

        oled.dev.clearDisplay();
        oled.dev.setTextSize(1);
        oled.dev.setTextColor(SSD1306_WHITE);
        oled.dev.setCursor(0, 0);
        oled.dev.println("COMPASS CAL");
        oled.dev.println("ROTATE SENSOR");
        oled.dev.print("Time: "); oled.dev.print(remain); oled.dev.print("s");
        oled.dev.display();

        while (PAA_SERIAL.available() && cal_resp_len < 127) {
            char c = PAA_SERIAL.read();
            cal_resp[cal_resp_len++] = c;
            cal_resp[cal_resp_len]   = '\0';
        }
        if (strstr(cal_resp, "ok ") || strstr(cal_resp, "\nok")) {
            got_ok = true;
            break;
        }
        delay(500);
    }

    // 顯示結果
    oled.dev.clearDisplay();
    oled.dev.setTextSize(2);
    oled.dev.setCursor(0, 8);
    oled.dev.println(got_ok ? "CAL OK" : "CAL FAIL");
    oled.dev.display();
    delay(2000);

    // 重啟資料輸出
    while (PAA_SERIAL.available()) PAA_SERIAL.read();
    uart_len = 0;
    PAA_SERIAL.println("atx+");
    delay(200);

    redrawStateScreen(false);
}

bool autoFit(int sz, int pad, FitCtx &out) {
    if (pt_count < 2) return false;

    float raw_mn_x = raw_pts[0].x, raw_mx_x = raw_pts[0].x;
    float raw_mn_y = raw_pts[0].y, raw_mx_y = raw_pts[0].y;
    for (int i = 0; i < pt_count; i++) {
        fit_work_x[i] = raw_pts[i].x;
        fit_work_y[i] = raw_pts[i].y;
        if (raw_pts[i].x < raw_mn_x) raw_mn_x = raw_pts[i].x;
        if (raw_pts[i].x > raw_mx_x) raw_mx_x = raw_pts[i].x;
        if (raw_pts[i].y < raw_mn_y) raw_mn_y = raw_pts[i].y;
        if (raw_pts[i].y > raw_mx_y) raw_mx_y = raw_pts[i].y;
    }

    qsort(fit_work_x, pt_count, sizeof(float), compareFloatAsc);
    qsort(fit_work_y, pt_count, sizeof(float), compareFloatAsc);

    int trim = (pt_count >= 20) ? (pt_count / 20) : 0;  // trim 5% extreme points
    if (trim * 2 >= pt_count) trim = 0;

    float mn_x = fit_work_x[trim];
    float mx_x = fit_work_x[pt_count - 1 - trim];
    float mn_y = fit_work_y[trim];
    float mx_y = fit_work_y[pt_count - 1 - trim];

    if (mx_x <= mn_x) { mn_x = raw_mn_x; mx_x = raw_mx_x; }
    if (mx_y <= mn_y) { mn_y = raw_mn_y; mx_y = raw_mx_y; }

    float w = mx_x - mn_x;
    float h = mx_y - mn_y;
    float fit = (float)(sz - pad * 2);
    float sc;
    if      (w == 0 && h == 0) sc = 1.0f;
    else if (w == 0)           sc = fit / h;
    else if (h == 0)           sc = fit / w;
    else                       sc = (fit / w < fit / h) ? fit / w : fit / h;

    float cx = (mn_x + mx_x) * 0.5f;
    float cy = (mn_y + mx_y) * 0.5f;
    float c  = (float)sz * 0.5f;
    for (int i = 0; i < pt_count; i++) {
        out.px[i] = (int)(c + (raw_pts[i].x - cx) * sc + 0.5f);
        out.py[i] = (int)(c - (raw_pts[i].y - cy) * sc + 0.5f);
    }
    out.scale = sc;
    return true;
}

static inline void plotBmp3px(int x, int y) {
    for (int dy = -1; dy <= 1; dy++) {
        int py = y + dy;
        if (py < 0 || py >= BMP_SIZE) continue;
        for (int dx = -1; dx <= 1; dx++) {
            int px = x + dx;
            if (px < 0 || px >= BMP_SIZE) continue;
            bmp[py][px] = 1;
        }
    }
}

void bmpLine(int x0, int y0, int x1, int y1) {
    int dx = abs(x1 - x0), dy = abs(y1 - y0);
    int sx = x0 < x1 ? 1 : -1;
    int sy = y0 < y1 ? 1 : -1;
    int err = dx - dy;

    while (true) {
        if (x0 >= 0 && x0 < BMP_SIZE && y0 >= 0 && y0 < BMP_SIZE) plotBmp3px(x0, y0);
        if (x0 == x1 && y0 == y1) break;
        int e2 = 2 * err;
        if (e2 > -dy) { err -= dy; x0 += sx; }
        if (e2 <  dx) { err += dx; y0 += sy; }
    }
}

void renderToBmp(const FitCtx &fc) {
    memset(bmp, 0, sizeof(bmp));
    for (int i = 1; i < pt_count; i++) {
        if (stroke_start[i]) continue;
        bmpLine(fc.px[i - 1], fc.py[i - 1], fc.px[i], fc.py[i]);
    }
}

void clearStrokes() {
    pt_count = 0;
    stroke_cnt = 0;
    debug_pts_dropped = 0;
    memset(raw_pts, 0, sizeof(raw_pts));
    memset(stroke_start, 0, sizeof(stroke_start));
    memset(bmp, 0, sizeof(bmp));
    memset(recog_bmp, 0, sizeof(recog_bmp));
    memset(&fit_ctx, 0, sizeof(fit_ctx));
    memset(fit_work_x, 0, sizeof(fit_work_x));
    memset(fit_work_y, 0, sizeof(fit_work_y));
}


static void *jpegOpen(const char *path) {
    return fopen(path, "w+b");
}

static void jpegClose(JPEGE_FILE *pFile) {
    FILE *fp = (FILE *)pFile->fHandle;
    if (fp) fclose(fp);
}

static int32_t jpegRead(JPEGE_FILE *pFile, uint8_t *buffer, int32_t length) {
    FILE *fp = (FILE *)pFile->fHandle;
    if (!fp) return 0;
    return (int32_t)fread(buffer, 1, (size_t)length, fp);
}

static int32_t jpegWrite(JPEGE_FILE *pFile, uint8_t *buffer, int32_t length) {
    FILE *fp = (FILE *)pFile->fHandle;
    if (!fp) return 0;
    return (int32_t)fwrite(buffer, 1, (size_t)length, fp);
}

static int32_t jpegSeek(JPEGE_FILE *pFile, int32_t position) {
    FILE *fp = (FILE *)pFile->fHandle;
    if (!fp) return -1;
    if (fseek(fp, position, SEEK_SET) != 0) return -1;
    return (int32_t)ftell(fp);
}
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
void loop() {
    handleButtonEvent(pollButton());

    while (Serial.available()) {
        char c = (char)Serial.read();
        if (c == '\n' || c == '\r') {
            if (cmd_len > 0) {
                cmd_buf[cmd_len] = '\0';
                PAA_SERIAL.println(cmd_buf);
                cmd_len = 0;
            }
        } else if (cmd_len < (int)sizeof(cmd_buf) - 1) {
            cmd_buf[cmd_len++] = c;
        }
    }

    static uint32_t _hb = 0;
    if (millis() - _hb > 5000) {
        _hb = millis();
    }

    static uint32_t _paa_last = 0;
    static bool _paa_warned = false;
    static bool _paa_init = false;
    if (!_paa_init) {
        _paa_last = millis();
        _paa_init = true;
    }

    while (PAA_SERIAL.available()) {
        handleButtonEvent(pollButton());
        _paa_last = millis();
        _paa_warned = false;
        char c = (char)PAA_SERIAL.read();
        if (c == '\n' || c == '\r') {
            if (uart_len > 0) {
                uart_buf[uart_len] = '\0';
                processLine(uart_buf);
                uart_len = 0;
            }
        } else if (uart_len < (int)sizeof(uart_buf) - 1) {
            uart_buf[uart_len++] = c;
        }
    }

    if (millis() - _paa_last > 3000) {
        if (!_paa_warned) {
            showStatusScreen("PAA PROCESSING", "RETRY...");
            Serial.println("[PAA] no data, retry init");
            _paa_warned = true;
        }
        while (PAA_SERIAL.available()) PAA_SERIAL.read();
        uart_len = 0;
        if (initPAA()) {
            redrawStateScreen(false);
            _paa_warned = false;
        } else {
            Serial.println("[PAA] retry failed");
        }

        _paa_last = millis();
    }

    if (recognize_pending && run_state != RUN_RECOGNIZING) {
        onRecognize();
    }
}

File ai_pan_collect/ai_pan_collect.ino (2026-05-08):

/*
 * ai_pan_collect.ino
 * 訓練資料集收集（無推論、無重啟）
 *
 * OLED 佈局：
 *   [SEC0: 路徑預覽] | [SEC1: 目標字元] [SEC2-3: 目前數量]
 *
 * 操作：
 *   長按   → 開始畫字
 *   放開   → 停筆
 *   雙擊   → 暫存 1 張；累積 10 張後批次儲存 BMP
 *   三擊   → 清除筆跡（不儲存）
 *
 * Serial 指令：
 *   <class_idx>-<sample_idx>  例：3-79  從 class 3 第 79 張繼續
 *   class 0~13 對應 0 1 2 3 4 5 6 7 8 9 + - × ÷
 */

#include <Wire.h>
#include "OledDisplay.h"

// 覆蓋 OledDisplay.h 的預設值，收集程式使用較大解析度
#undef BMP_SIZE
#define BMP_SIZE 192
#undef BMP_PAD
#define BMP_PAD  20

#ifdef __cplusplus
extern "C" {
#endif
#include "vfs.h"
#ifdef __cplusplus
}
#endif

// ── 硬體定義 ─────────────────────────────────────────────────────
#define BTN              15
#define LONG_PRESS_MS  300
#define DOUBLE_CLICK_MS 350

#define PAA_SERIAL  Serial3
#define PAA_BAUD    115200

// ── 資料集設定 ────────────────────────────────────────────────────
#define SD_DATASET_DIR    "sd:/dataset"
#define SAMPLES_PER_CLASS 50
#define MAX_PTS           800
#define BATCH_SAVE_COUNT   10

static const char *LABELS[14] = {
    "0","1","2","3","4","5","6","7","8","9",
    "+","-","x","/"
};
static const char *SAFE_NAMES[14] = {
    "0","1","2","3","4","5","6","7","8","9",
    "add","sub","mul","div"
};
#define NUM_CLASSES 14

// ── 全域物件 ──────────────────────────────────────────────────────
OledDisplay oled;

Pt   raw_pts[MAX_PTS];
bool stroke_start[MAX_PTS];
int  pt_count   = 0;
int  stroke_cnt = 0;

uint8_t bmp[BMP_SIZE][BMP_SIZE];

struct FitCtx { int px[MAX_PTS]; int py[MAX_PTS]; float scale; };
static FitCtx  fit_ctx;
static float   fit_work_x[MAX_PTS];
static float   fit_work_y[MAX_PTS];
struct PendingSample {
    Pt pts[MAX_PTS];
    uint8_t stroke_start[MAX_PTS];
    uint16_t pt_count;
    uint16_t class_idx;
    uint16_t sample_idx;
};
static PendingSample pending_samples[BATCH_SAVE_COUNT];
static int pending_count = 0;

static bool     is_writing         = false;
static bool     first_pt_of_stroke = false;
static bool     is_batch_saving    = false;

static int cur_class  = 0;
static int cur_sample = 0;

enum BtnEvt { BTN_NONE, BTN_LONG_START, BTN_LONG_END, BTN_SINGLE, BTN_DOUBLE, BTN_TRIPLE };
static bool     _prev_btn     = HIGH;
static bool     _in_long      = false;
static uint32_t _press_t      = 0;
static uint32_t _last_click_t = 0;
static uint8_t  _click_count  = 0;

char uart_buf[128]; int uart_len = 0;
char cmd_buf[128];  int cmd_len  = 0;

// ── 顯示 ─────────────────────────────────────────────────────────
void drawCount() {
    char s[4];
    snprintf(s, sizeof(s), "%03d", cur_sample);
    oled.secBigChar(2, s[0]);          // 百位
    char s2[3] = { s[1], s[2], '\0' };
    oled.secFitText(3, s2);            // 十位+個位
}

void drawCountValue(int sample_idx) {
    char s[4];
    snprintf(s, sizeof(s), "%03d", sample_idx);
    oled.secBigChar(2, s[0]);
    char s2[3] = { s[1], s[2], '\0' };
    oled.secFitText(3, s2);
}

void redrawMain(bool show_preview) {
    oled.dev.clearDisplay();
    if (show_preview && pt_count > 0)
        oled.drawSec0Preview(raw_pts, stroke_start, pt_count);
    else
        oled.clearSec(0);
    oled.secBigChar(1, LABELS[cur_class][0]);
    drawCount();
    oled.drawDividers();
    oled.dev.display();
}

void redrawSavingStatus(int class_idx, int sample_idx, int done, int total) {
    char progress[8];
    snprintf(progress, sizeof(progress), "%d/%d", done, total);

    oled.dev.clearDisplay();
    oled.secSmallText(0, "Saving", progress);
    oled.secBigChar(1, LABELS[class_idx][0]);
    drawCountValue(sample_idx);
    oled.drawDividers();
    oled.dev.display();
}

// ── 按鈕 ─────────────────────────────────────────────────────────
BtnEvt pollButton() {
    bool cur = digitalRead(BTN);
    uint32_t now = millis();
    BtnEvt evt = BTN_NONE;

    if (cur == LOW && _prev_btn == HIGH) {
        _press_t = now;
    } else if (cur == HIGH && _prev_btn == LOW) {
        if (_in_long) {
            _in_long = false;
            evt = BTN_LONG_END;
        } else if (now - _press_t < LONG_PRESS_MS) {
            if (_click_count < 3) _click_count++;
            _last_click_t = now;
        }
    } else if (cur == LOW) {
        if (!_in_long && (now - _press_t >= LONG_PRESS_MS)) {
            _in_long = true;
            _click_count = 0;
            evt = BTN_LONG_START;
        }
    } else if (_click_count > 0 && (now - _last_click_t >= DOUBLE_CLICK_MS)) {
        if      (_click_count == 1) evt = BTN_SINGLE;
        else if (_click_count == 2) evt = BTN_DOUBLE;
        else if (_click_count >= 3) evt = BTN_TRIPLE;
        _click_count = 0;
    }

    _prev_btn = cur;
    return evt;
}

// ── 筆跡 / BMP ───────────────────────────────────────────────────
static int cmpFloat(const void *a, const void *b) {
    float fa = *(const float *)a, fb = *(const float *)b;
    return (fa < fb) ? -1 : (fa > fb) ? 1 : 0;
}

bool autoFit(const Pt *pts, int count, FitCtx &out) {
    if (count < 2) return false;
    float rmx = pts[0].x, rMx = pts[0].x;
    float rmy = pts[0].y, rMy = pts[0].y;
    for (int i = 0; i < count; i++) {
        fit_work_x[i] = pts[i].x;
        fit_work_y[i] = pts[i].y;
        if (pts[i].x < rmx) rmx = pts[i].x;
        if (pts[i].x > rMx) rMx = pts[i].x;
        if (pts[i].y < rmy) rmy = pts[i].y;
        if (pts[i].y > rMy) rMy = pts[i].y;
    }
    qsort(fit_work_x, count, sizeof(float), cmpFloat);
    qsort(fit_work_y, count, sizeof(float), cmpFloat);
    int trim = (count >= 20) ? count / 20 : 0;
    if (trim * 2 >= count) trim = 0;
    float mn_x = fit_work_x[trim],        mx_x = fit_work_x[count-1-trim];
    float mn_y = fit_work_y[trim],        mx_y = fit_work_y[count-1-trim];
    if (mx_x <= mn_x) { mn_x = rmx; mx_x = rMx; }
    if (mx_y <= mn_y) { mn_y = rmy; mx_y = rMy; }
    float w = mx_x - mn_x, h = mx_y - mn_y;
    float fit = (float)(BMP_SIZE - BMP_PAD * 2);
    float sc = (w == 0 && h == 0) ? 1.0f
             : (w == 0) ? fit / h
             : (h == 0) ? fit / w
             : (fit/w < fit/h) ? fit/w : fit/h;
    float cx = (mn_x+mx_x)*0.5f, cy = (mn_y+mx_y)*0.5f, c = BMP_SIZE*0.5f;
    for (int i = 0; i < count; i++) {
        out.px[i] = (int)(c + (pts[i].x - cx) * sc + 0.5f);
        out.py[i] = (int)(c - (pts[i].y - cy) * sc + 0.5f);
    }
    out.scale = sc;
    return true;
}

void bmpDot(int x, int y) {
    // 3×3 方塊筆畫（stroke width ≈ 3px）
    for (int dr = -1; dr <= 1; dr++)
        for (int dc = -1; dc <= 1; dc++) {
            int px = x + dc, py = y + dr;
            if (px >= 0 && px < BMP_SIZE && py >= 0 && py < BMP_SIZE)
                bmp[py][px] = 1;
        }
}

void bmpLine(int x0, int y0, int x1, int y1) {
    int dx=abs(x1-x0), dy=abs(y1-y0);
    int sx=x0<x1?1:-1, sy=y0<y1?1:-1, err=dx-dy;
    while (true) {
        bmpDot(x0, y0);
        if (x0==x1&&y0==y1) break;
        int e2=2*err;
        if (e2>-dy){err-=dy;x0+=sx;}
        if (e2< dx){err+=dx;y0+=sy;}
    }
}
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

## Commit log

2026-05-08 ai pen
    [ai_pan_frame_board.stl]
2026-05-12 code update
    [ai_pan_frame_board.stl]
